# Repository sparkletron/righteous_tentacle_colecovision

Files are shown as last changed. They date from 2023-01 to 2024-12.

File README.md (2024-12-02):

# Righteous Tentacle, Colecovision Reverse Engineering Project
### Schematic and PCB reproduction.

---

  author: Jay Convertino

  date: 2023.03.01

  details: Reverse engineer original PCB to create a schematic and functional replacment board. This only includes the NTSC system.

  license: MIT

---

PCB_Complete|300

## LICENSE
  - All files related to or generated from the KiCAD source fall under the MIT license.
  - All files generated by me, Jay Convertino, fall under the MIT license.
  - All files from other sources fall under the license of their specification.

## RELEASE VERSIONS
### Current
  - 1.0.2.F - Fixed solder mask on expansion bay connector.

### Past
  - 1.0.1.F - Added power and reset switch to case.
  - 1.0.0.F - initial release of revision F main PCB
  - DEV

## Gerbers
  Files available below, to download select the download icon next to the raw icon on right hand upper side of the page.
  - [Main PCB Gerber Archive](schematic/PCB_TOOLS/gerber/MAIN_GERBER.zip)
  - [RF PCB Gerber Archive](schematic/PCB_TOOLS/gerber/RF_GERBER.zip)

## Wiki
  - Please see the [Wiki](../../wiki) for various information.
    - Contains howto's, build notes, bill of materials, project logs, and signal documentation.

## Parts list
  - [Link to Wiki Parts list for the original console](../../wiki/Detailed-Part-Listing-For-Original)
  - [Link to Wiki Parts list for ordering parts](../../wiki/Detailed-Part-Listing-For-Orders)

## Intro

  This recreation of the PCB is for documenation, and reproduction purposes. This mimicks the PCB of the original NTSC revision F main board.

## SOURCES
### Schematic Check
  - Atari HQ Schematic : https://wiki.console5.com/wiki/Colecovision : Dan Boris
  - Atari Age : https://forums.atariage.com/topic/285656-new-colecovision-schematics/ : ChildOfCV

  Special thanks to ChildOfCV. Using his as a check for mine after buzzing out my own board was a great help. His schematic on
  its own is a great resource.

  Did find a few issues with mine vs the ChildOfCV version, my board is a different revision so they will differ in subtle ways.
  Seems to be mostly just cap and resistor values in the RF circuit. Though I did adjust my values on the clock to reflect those
  recommend in the tech manual.

  The Dan Boris schematic is ok, has a few mistakes that I can't recall at the moment. Mentioning it since I did look at it, but
  due to its issues I didn't use it.

## REQUIREMENTS
  - KiCAD v7.X

## BUILD TIPS
  This design is made so anyone can build this. You may send it out to a fab house, you may use a PCB mill, or even etch it.
  This is possible since the components can serve as the plated through hole. Other holes can simply have a solid piece of
  wire inserted and soldered to complete the connection (excess resistor leads is a great option).

  Recommend soldering the cartridge connector first, the CPU makes soldering one side of the pins a bit difficult to do
  without melting the connector.

  There are various questionable routings, these are how the original is done. Some adjustments were made to make some things easier
  for at home builders without plated through holes.

## FILE INFORMATION
  - README.md, is this file.
  - LICENSE.md, is the license file (MIT) for anything create by me, Jay Convertion, that resides in this repository.
  - doc, contains various documents used.
    - datasheets, contains parts used on the original board.
    - refs, sources used for checks
      - Coleco_ADAM_Schematic_-_Delta_Game.png, publicly available schematic of the ADAM
      - Coleco.zip, ChildOfCV schematic for the console and other various parts of the colecovision.
      - colecovision_atari_hq_schematic.pdf, Colecovision console schematic... has errors.
      - tms-doc-annotated.pdf, TMS design document corrected by Nicholas Piegdon
  - models, PCB items and case designes
    - component_search_engine, website 3D files
    - FreeCAD
      - MainBoard, 3D PCB export to step using freecad instead of kicad.
      - parts, parts designed for the PCB by myself and future contributions.
    - inventor_2024
      - base_case, contains ipt/stl files for building a case for the colecovision.
      - OldVersions, inventor files
    - partcommunity, website 3D files
    - kicad, kicad 3D pcb export to step.
  - pics, images take by me or others(watermark added) of the colecovision.
    - 3D, images generated by modeling tools.
    - built, contains all PCBs built
    - build_case, contains all completed cases with PCB.
    - control_pcb, pics of a different Colecovision console pcb (different REV) for comparison.
    - control_unit, pics of a different Colecovision console for comparison.
    - outside_sources, external sources with added watermark.
    - reverse_high_res, scans from a Canon 9600 DPI flatbed scanner of the PCB boards. Compressed to save space.
    - tear_down, images of the parts as they came apart.
    - signals
      - digital, all digital analyzer captures
      - analog, all analog scope captures
  - schematic, contains KiCAD schematic files.
    - coleco_original.kicad_pro, this file is the main project file that contains EVERTHING.
    - *-backups, are folders KiCAD creates to backup the project.
    - PCB_TOOLS
      - gerber, containts all exports from KiCAD
        - main, base PCB
        - rf, modulator PCB
      - GIMP_Placement_Tool, gimp project used to help place parts in the correct locations.
      - main, contains the main PCB extracted from the main project for production.
      - rf, contains RF PCB extracted from the main project for production.
    - lib, external components for KiCAD
      - CONNECTOR_PCBEdge_EXT
      - LOGOS
      - MHPS2273
      - MODELS
      - MOUNTS
      - OS102011MA1QN1
      - PADS
      - POWER_SYMBOLS
      - RCJ-041
      - RF_MODULATORS
      - SWITCHES_THT
      - TE_550841-2
      - VARIABLE_INDUCTORS
      - VINTAGE_AUDIO_SYNTH
      - VINTAGE_RAM
      - VINTAGE_VDP
    - PDF, various KiCAD exports in the PDF format. PCB and/or schematics.

## PCB IMAGE

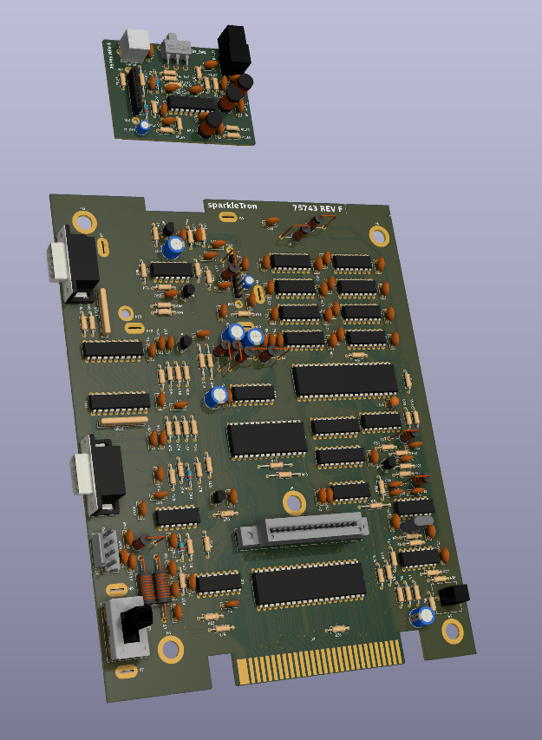
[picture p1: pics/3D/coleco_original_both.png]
pcb_3D_img|300


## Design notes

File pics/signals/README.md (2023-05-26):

# SIGNALS INFO

## Folders
- Analog
All signals in the analog folder are measured using an oscilliscope probe, and include analog AND digitial signals self triggered as a single measurment.

- Digital
All signals in the digital folder are measured using a logic analyizer, and ONLY include digital signals.

## Usage
These captures are only for quick troubleshooting of the device. They are not perfect, though they give a rough idea of what someone should see. If they don't have something similar, there maybe a problem with signal.

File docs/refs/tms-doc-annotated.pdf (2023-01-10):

# Annotated by Nicholas Piegdon 2020-08-01

v1

Gain of two.
1 + 5k/5k = 2
Same components as the red
channel.

With a gain of
three, the blue
output becomes:
B ≈ Y + 2(B-Y)
Both Light Blue
and Dark Blue
will exceed 1.4V.
R54.

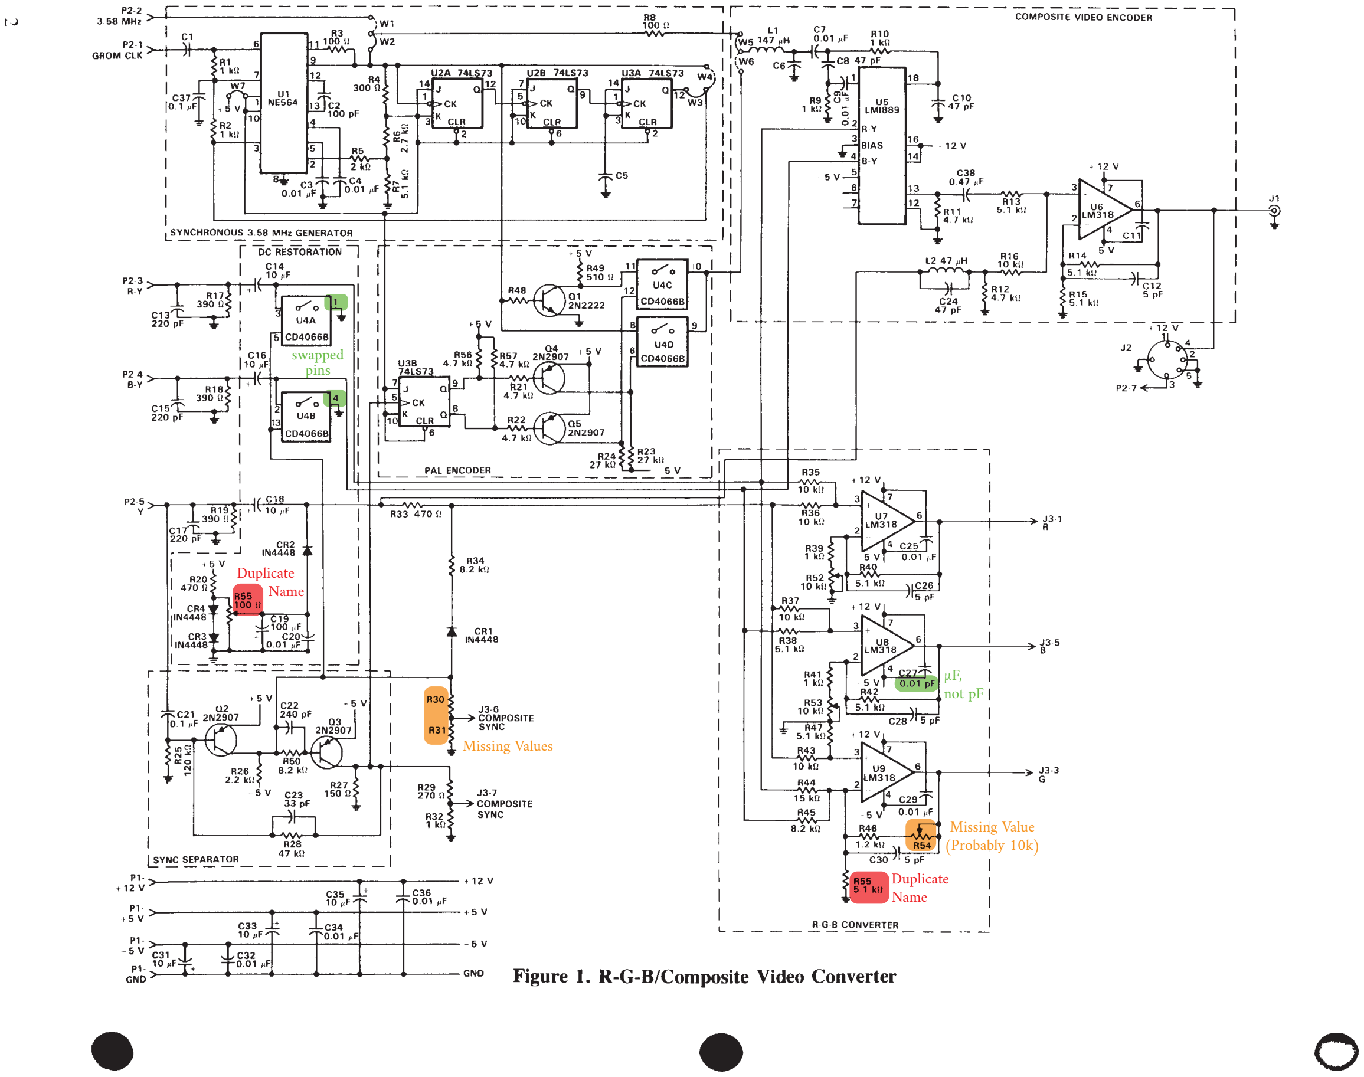
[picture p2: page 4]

Missing Values

Missing Value
(Probably 10k)

Duplicate
Name

Duplicate
Name

µF,
not pF

swapped
pins

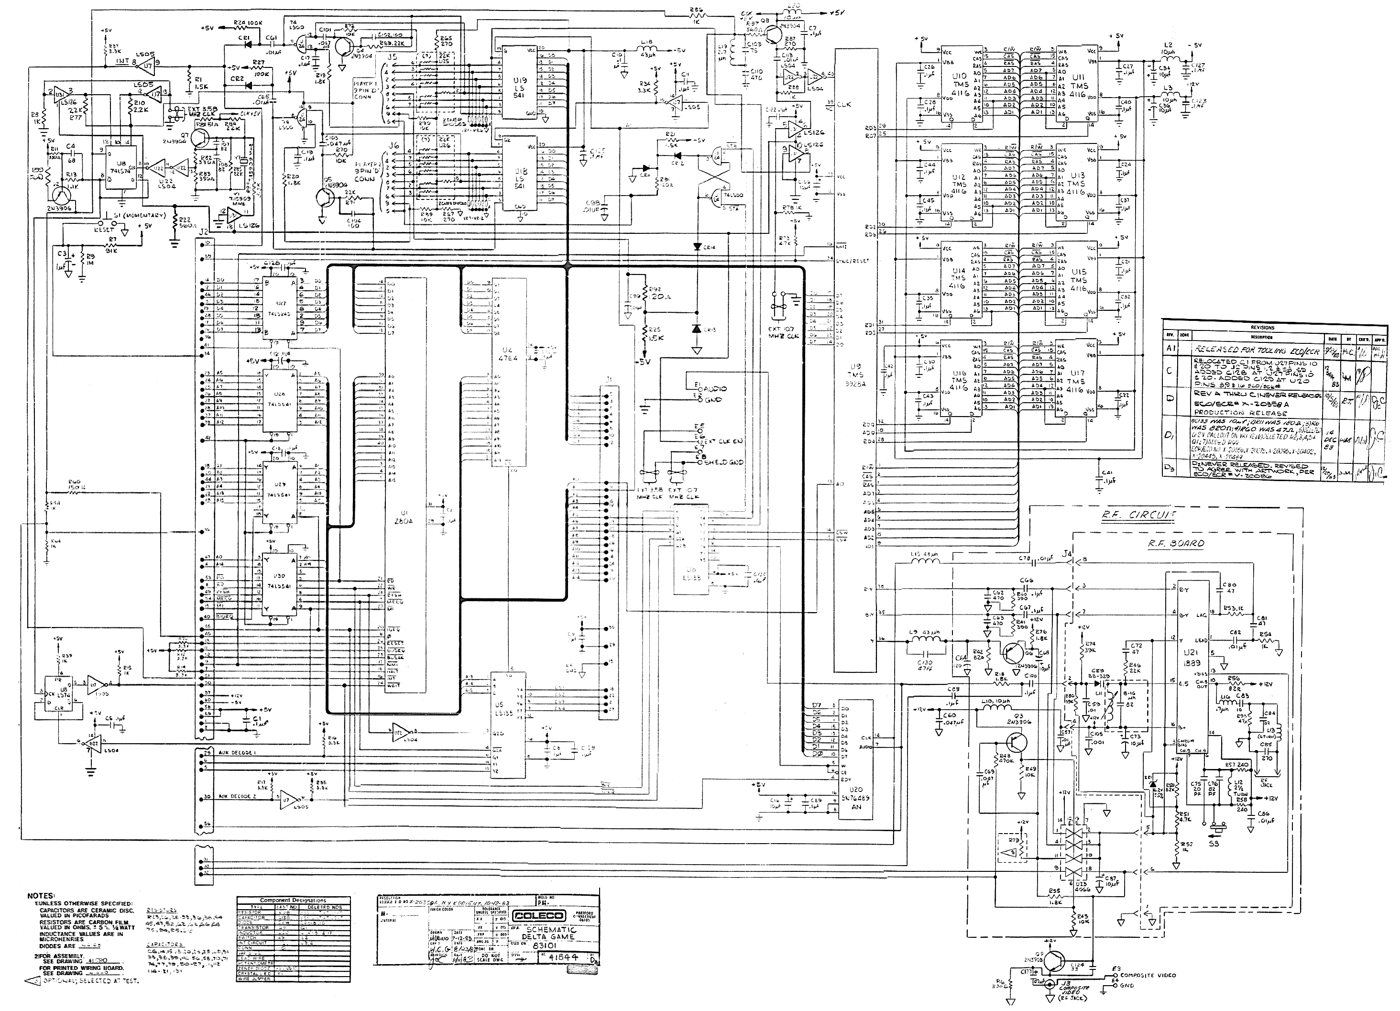
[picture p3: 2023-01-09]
docs/refs/Coleco_ADAM_Schematic_-_Delta_Game.png

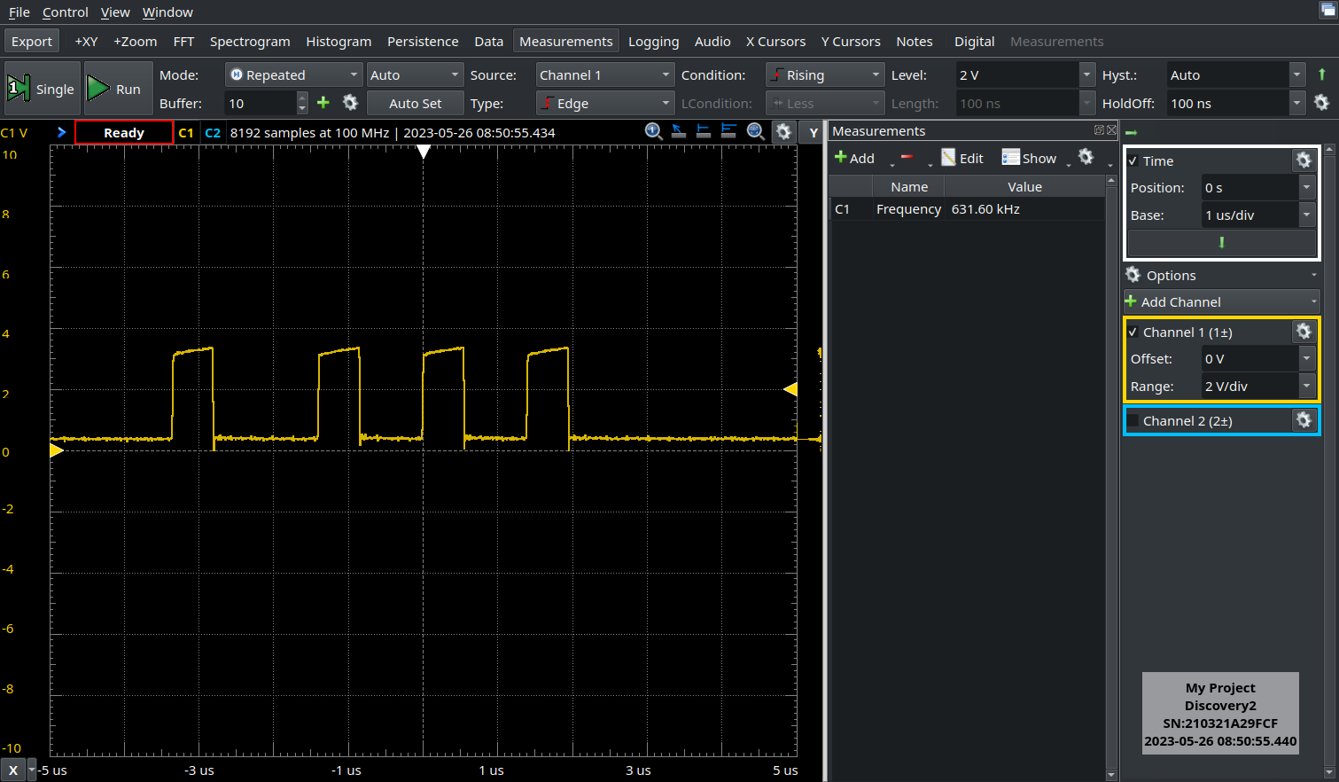
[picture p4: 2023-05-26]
pics/signals/analog/u22_12_rfsh_at_idle_no_game.png

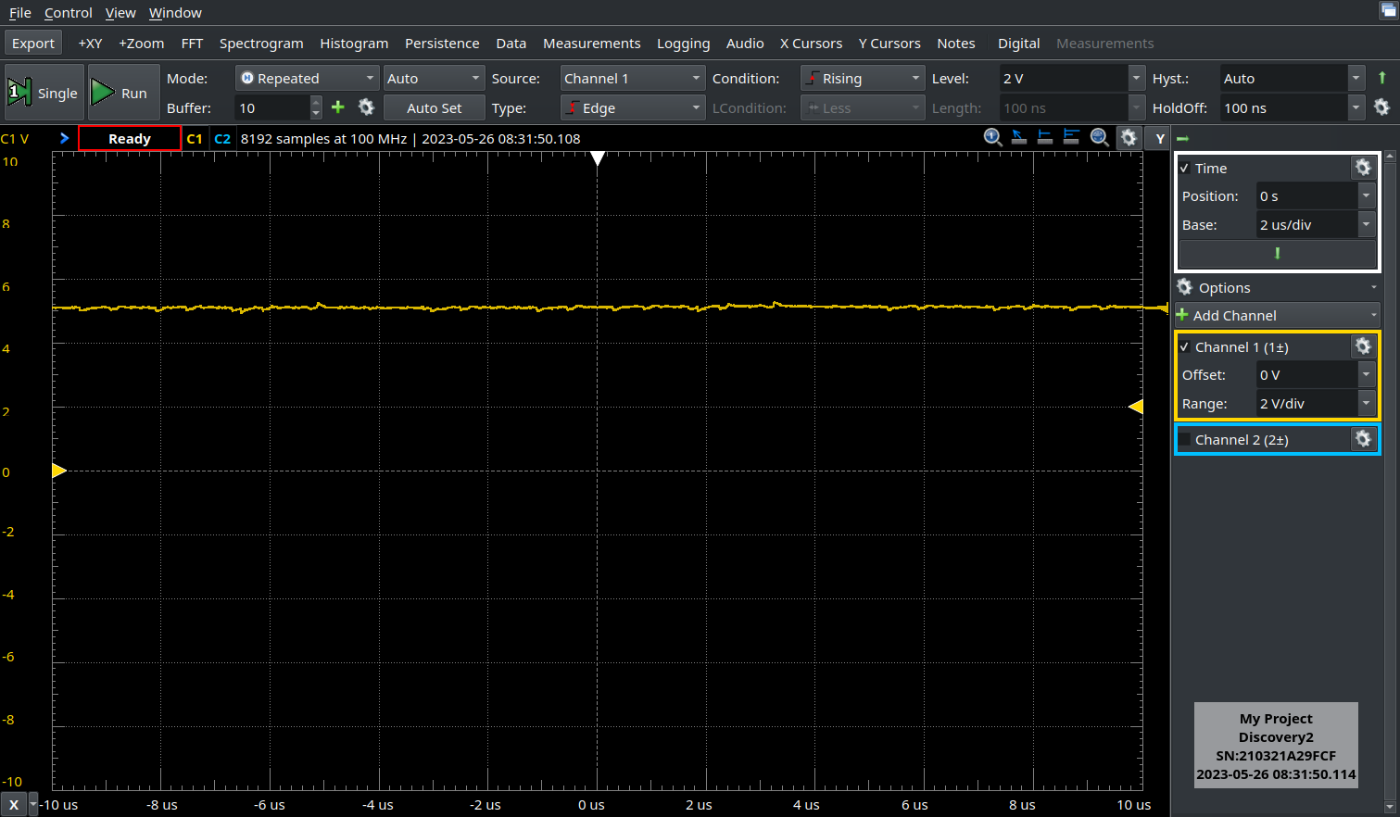
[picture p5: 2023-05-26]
pics/signals/analog/z80_int_at_idle_no_game.png

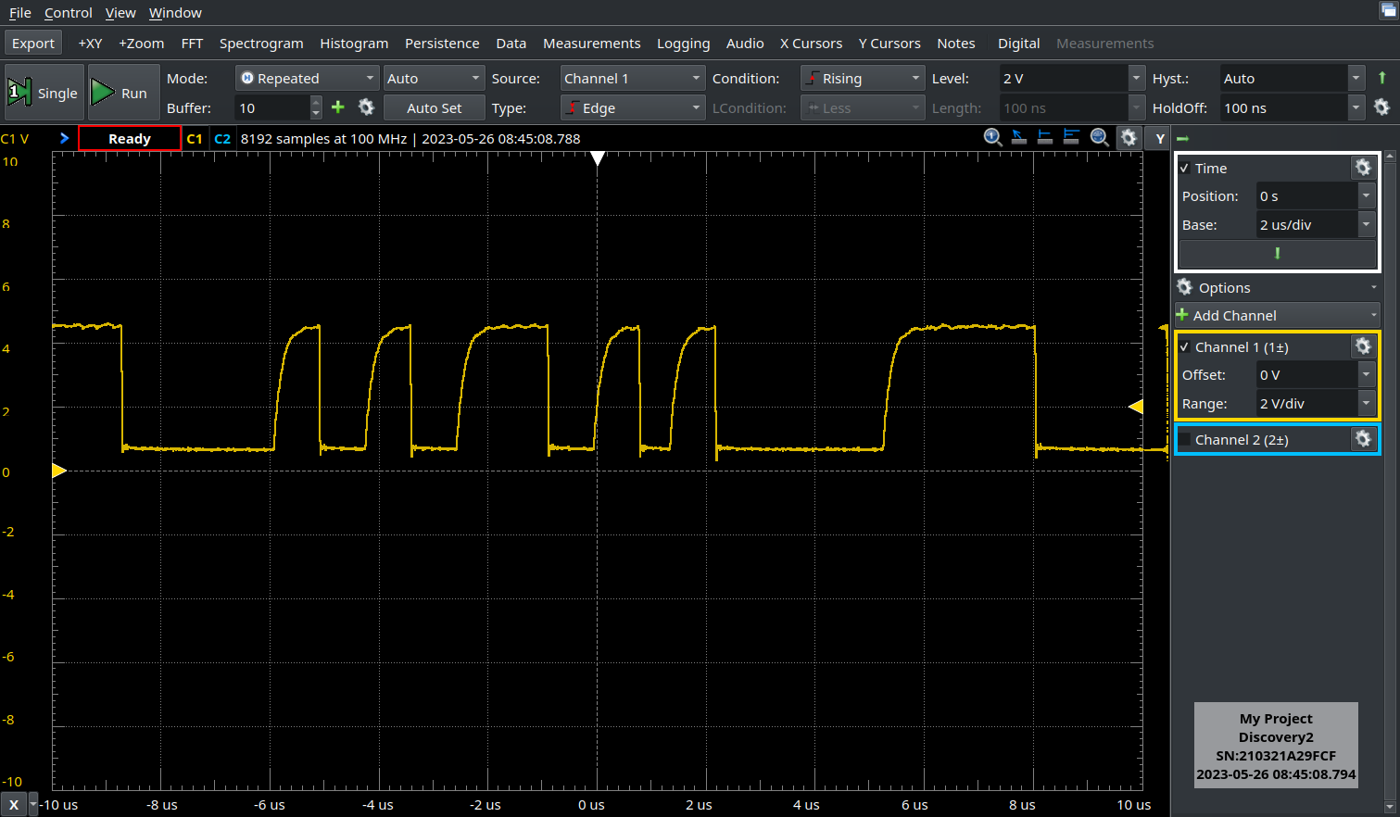
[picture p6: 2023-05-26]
pics/signals/analog/u7_2_ctrl_at_idle_no_game.png

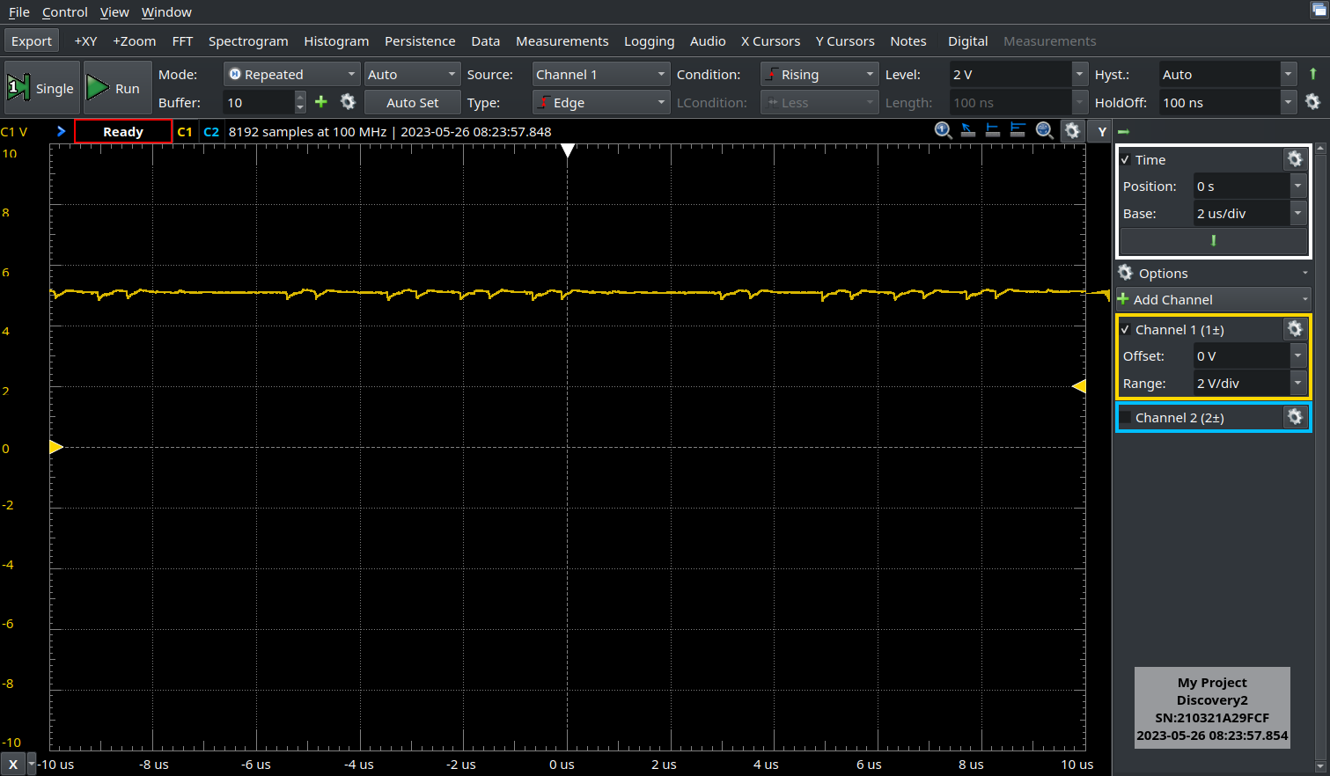
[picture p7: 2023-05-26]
pics/signals/analog/z80_busrq_at_idle_no_game.png

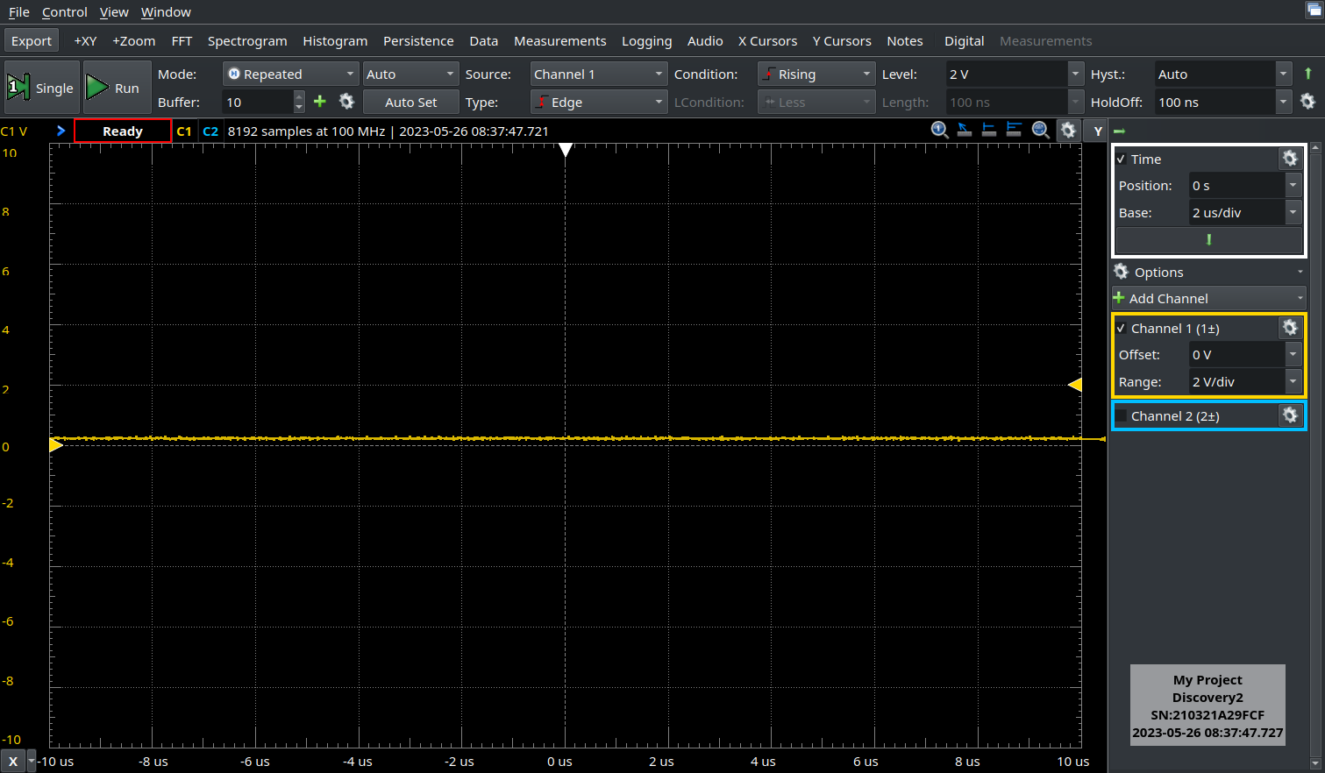
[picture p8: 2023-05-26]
pics/signals/analog/u7_6_aux_at_idle_no_game.png

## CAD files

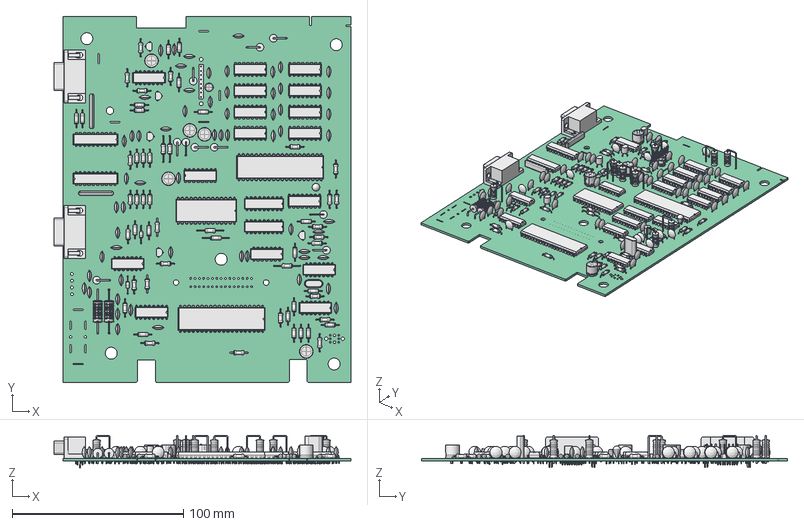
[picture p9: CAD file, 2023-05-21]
models/FreeCAD/MainBoard/main_exports_missing.FCStd
173.6 x 214.0 x 18.9 mm
Pcb_e821
C29_C_Disc_D70mm_W25mm_P500mm_226690d5e42f x 61
L6_L_Axial_L12.8mm_D5.8mm_P25.40mm_Horizontal_Fastron_HBCC_decbe469e87e x 2
R43_R_Axial_DIN0207_L63mm_D25mm_P1016mm_Horizontal_7cedd80d011b x 51
L7_L_Axial_L11.0mm_D4.5mm_P7.62mm_Vertical_Fastron_MECC_598f009e88d8 x 10
WJ1_R_Axial_DIN0207_L63mm_D25mm_P1524mm_Horizontal_ac59213be9fc x 5
C68_CP_Radial_D80mm_P500mm_57de8ce8222a x 5
U8_DIP-14_W7.62mm_df27ad89cb08 x 5
U17_DIP-16_W7.62mm_d55643cdfc89 x 11
J5_DSUB-9_Male_Horizontal_P2.77x2.84mm_EdgePinOffset7.70mm_Housed_ MountingHolesOffset9.12mm_0bdabfa7aa43 x 2
U3_DIP-18_W7.62mm_62ec9f861f82 x 2
UR25_R_Array_SIP8_bea4648dc058 x 2
Q5_TO-92_Wide_9f4aaa88ab23 x 5
Y1_Crystal_HC49-U_Vertical_6ec227dccee9
U18_DIP-20_W7.62mm_b5cb83710fea x 2
CR1_D_DO-35_SOD27_P10.16mm_Horizontal_de2f8e1b5c28 x 2
C87_CP_Radial_D50mm_P250mm_386abb8d7c83
J4A1_PinHeader_1x08_P254mm_Vertical_c9183c638373
C106_CP_Radial_Tantal_D45mm_P250mm_a5643c016bcc
U2_DIP-28_W15.24mm_3ebb076460d0
U9_DIP-40_W15.24mm_d9557ac351a7 x 2

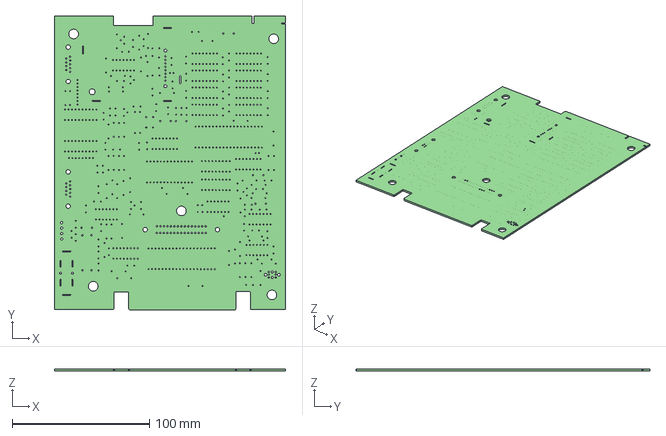
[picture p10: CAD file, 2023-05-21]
schematic/PCB_TOOLS/step/coleco_original_main_only.step
168.4 x 214.0 x 1.60 mm

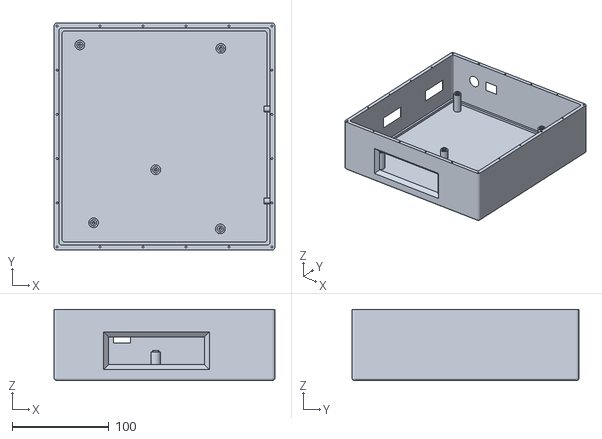
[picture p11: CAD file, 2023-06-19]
models/inventor_2024/Assembly1.stl
228.6 x 234.9 x 73.9

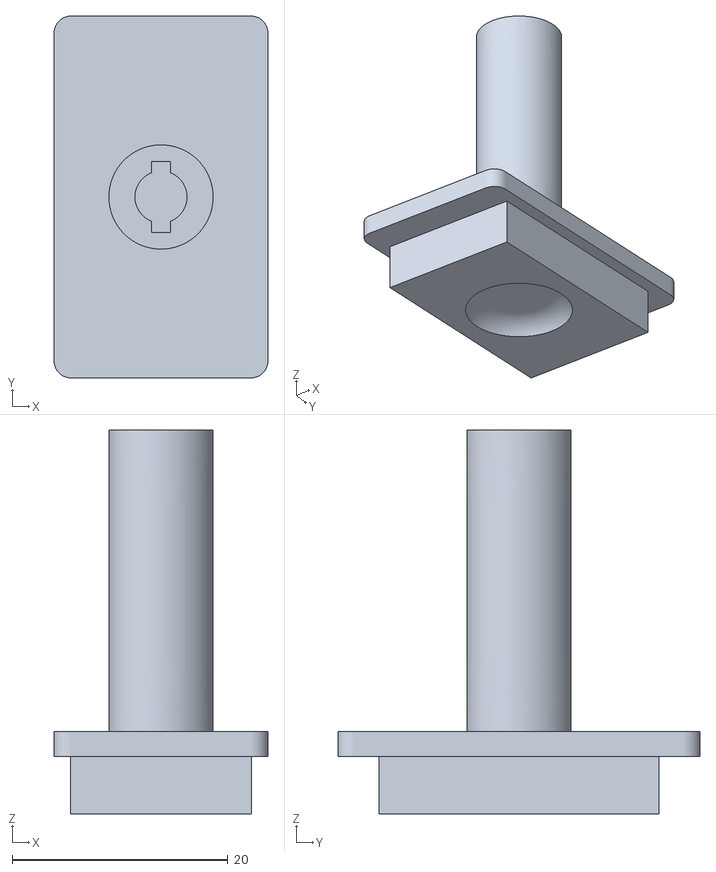
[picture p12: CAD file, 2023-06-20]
models/inventor_2024/base_case/reset_switch.stl
19.8 x 33.5 x 35.6

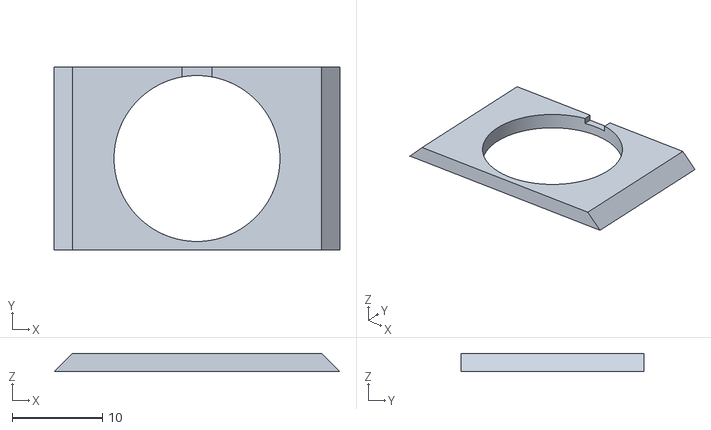
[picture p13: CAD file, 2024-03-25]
models/inventor_2024/org_case_psu_connector.stl
31.8 x 20.3 x 2.03

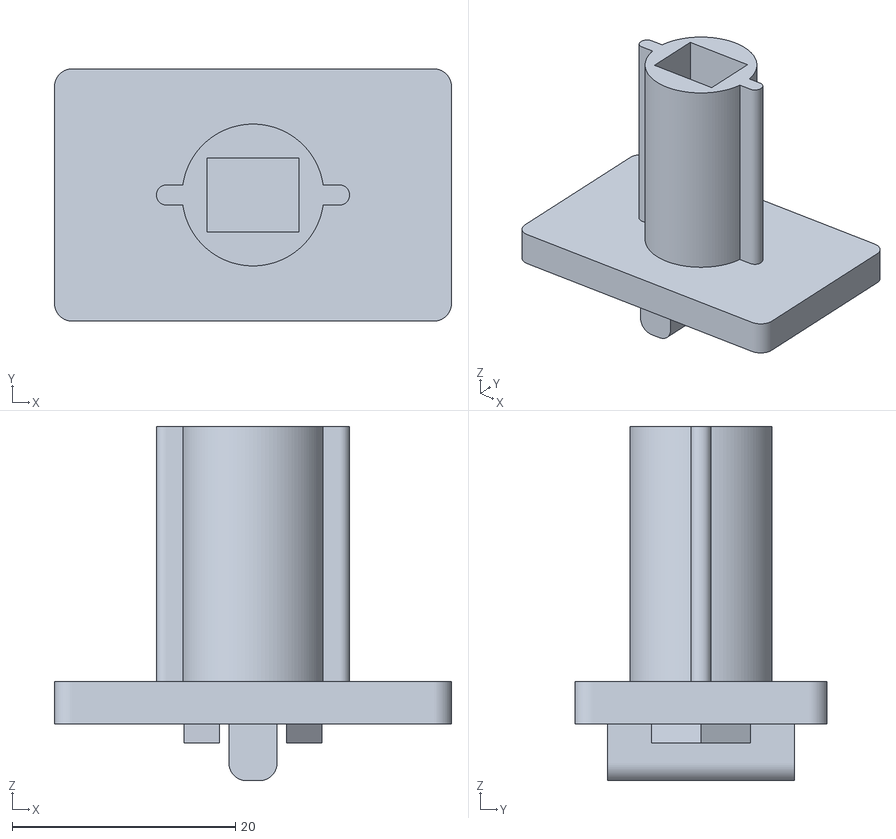
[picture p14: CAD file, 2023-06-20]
models/inventor_2024/base_case/power_switch.stl
35.6 x 22.6 x 31.8

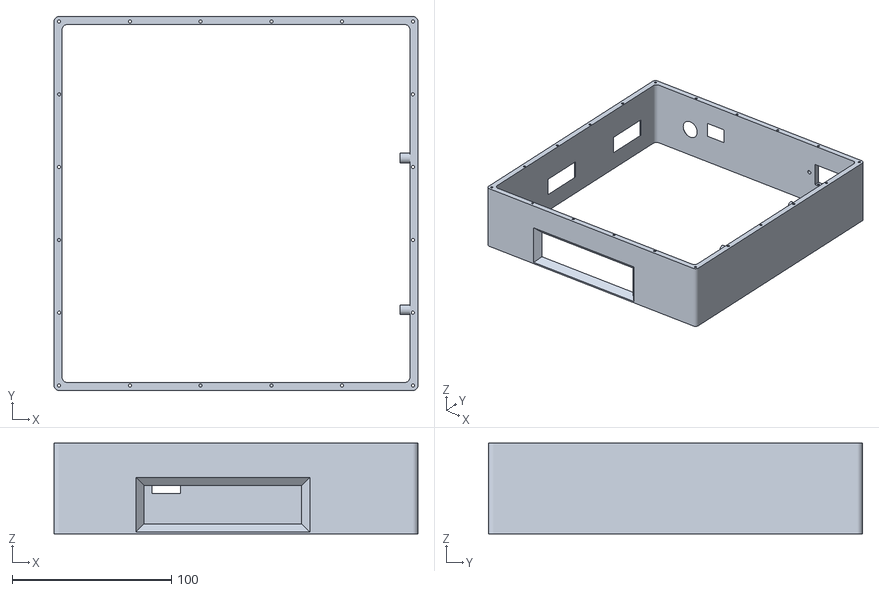
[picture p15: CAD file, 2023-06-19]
models/inventor_2024/base_case/middle_part.stl
228.6 x 234.9 x 57.2

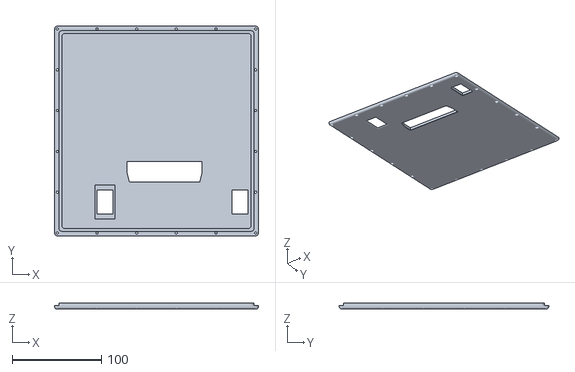
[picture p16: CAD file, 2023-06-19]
models/inventor_2024/base_case/top.stl
228.6 x 234.9 x 7.24

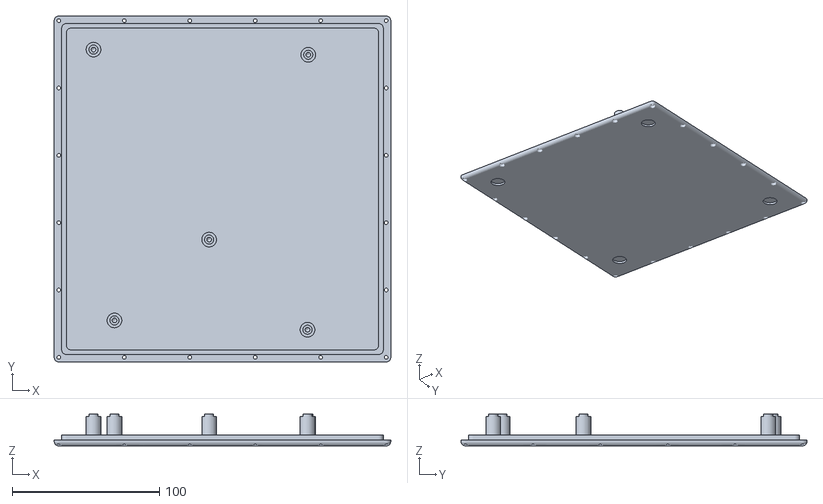
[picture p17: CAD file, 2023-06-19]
models/inventor_2024/base_case/bottom.stl
228.6 x 234.9 x 21.6

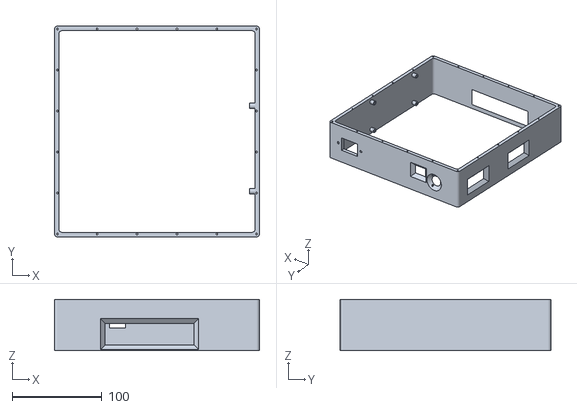
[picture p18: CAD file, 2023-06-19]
models/inventor_2024/base_case/middle.stl
228.6 x 235.0 x 57.2

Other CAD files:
models/FreeCAD/MainBoard/main_exports_missing-coleco_original_main_only/Board_Geoms_e821.iam
models/FreeCAD/MainBoard/main_exports_missing-coleco_original_main_only/C106_CP_Radial_Tantal_D45mm_P250mm_a5643c016bcc.ipt
models/FreeCAD/MainBoard/main_exports_missing-coleco_original_main_only/C29_C_Disc_D70mm_W25mm_P500mm_226690d5e42f.ipt
models/FreeCAD/MainBoard/main_exports_missing-coleco_original_main_only/C68_CP_Radial_D80mm_P500mm_57de8ce8222a.ipt
models/FreeCAD/MainBoard/main_exports_missing-coleco_original_main_only/C87_CP_Radial_D50mm_P250mm_386abb8d7c83.ipt
models/FreeCAD/MainBoard/main_exports_missing-coleco_original_main_only/CR1_D_DO-35_SOD27_P10.16mm_Horizontal_de2f8e1b5c28.ipt
models/FreeCAD/MainBoard/main_exports_missing-coleco_original_main_only/J4A1_PinHeader_1x08_P254mm_Vertical_c9183c638373.ipt
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

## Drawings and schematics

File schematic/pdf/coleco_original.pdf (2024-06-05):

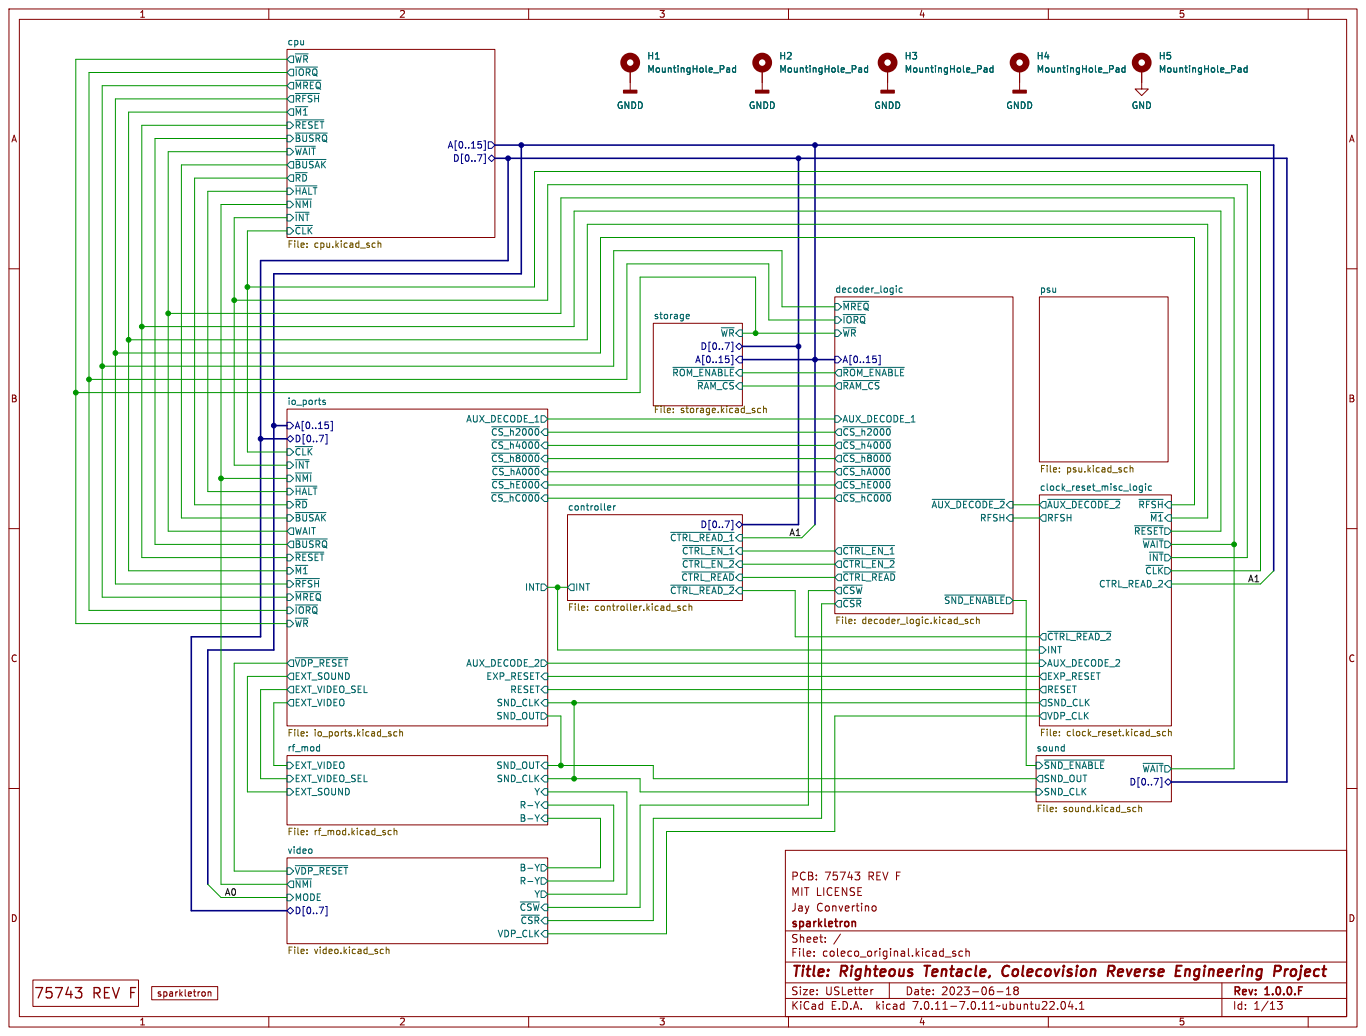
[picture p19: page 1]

Id: 1/13 Title: Righteous Tentacle, Colecovision Reverse Engineering Project File: coleco_original.kicad_sch Sheet: / sparkletron

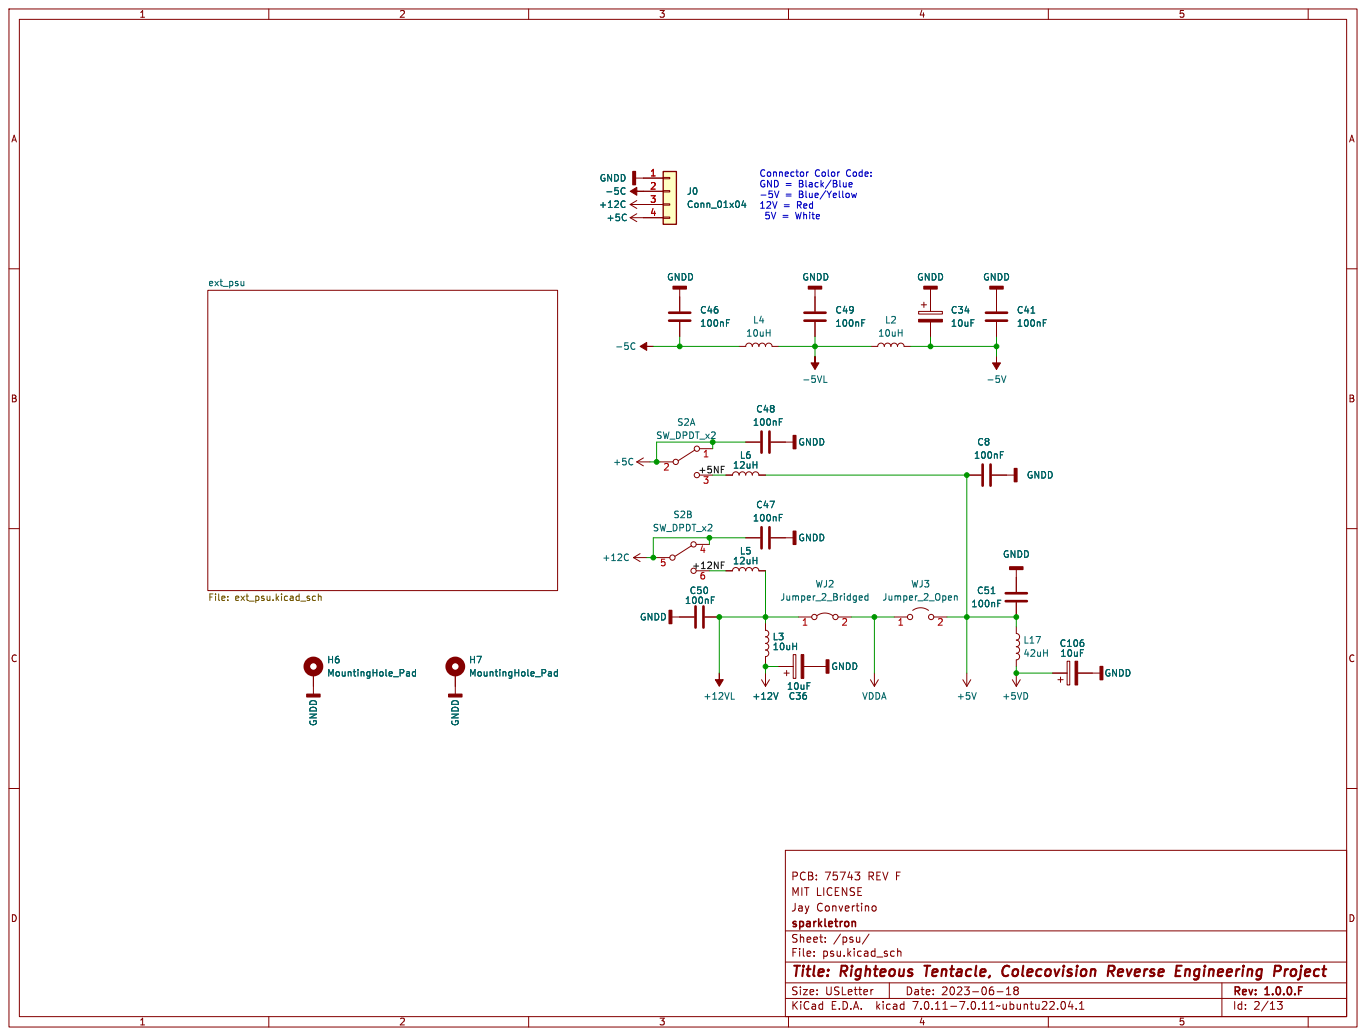
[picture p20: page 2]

Jay Convertino MIT sparkletron | LICENSE

E.D.A. kicad 7.0.11-7.0.11~ubuntu22.04.1 Size: USLetter Rev: 1.0.0.F Id: 2/13 Title: Righteous Tentacle, Colecovision Reverse Engineering Project File: psu.kicad_sch Sheet: /psu/ | D Date: 2023-06-18 KiCad

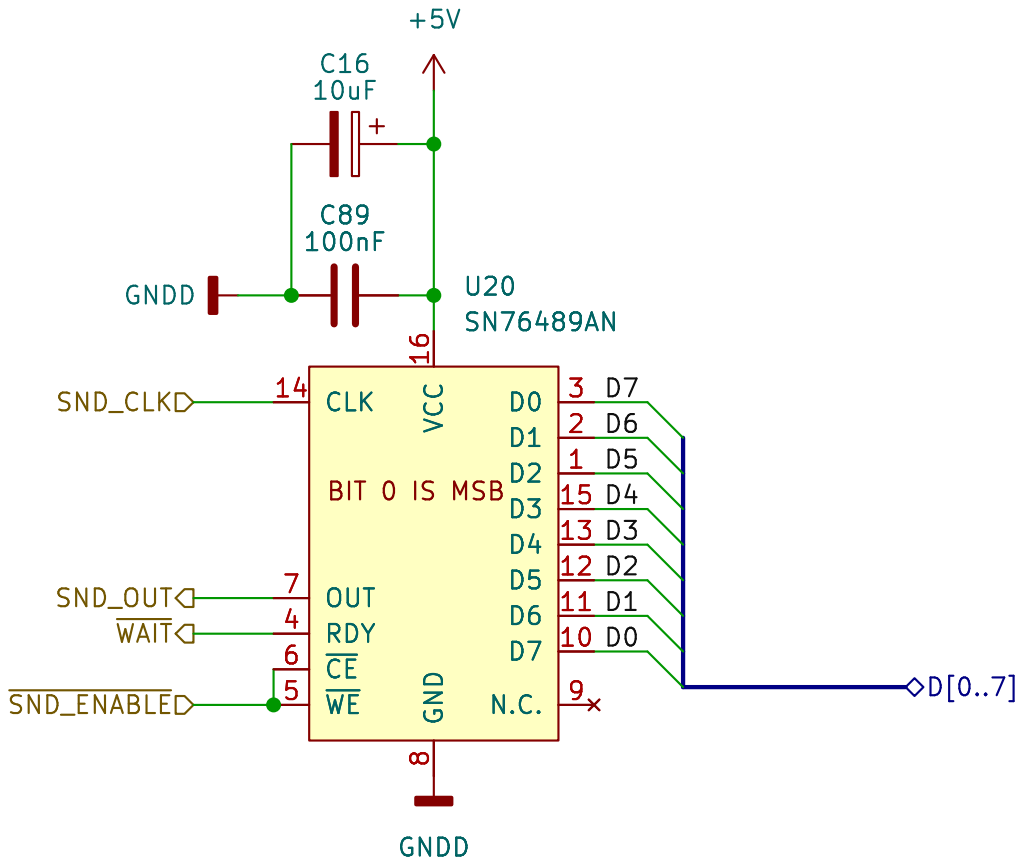
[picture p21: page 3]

Id: 4/13 Title: Righteous Tentacle, Colecovision Reverse Engineering Project File: sound.kicad_sch Sheet: /sound/ sparkletron

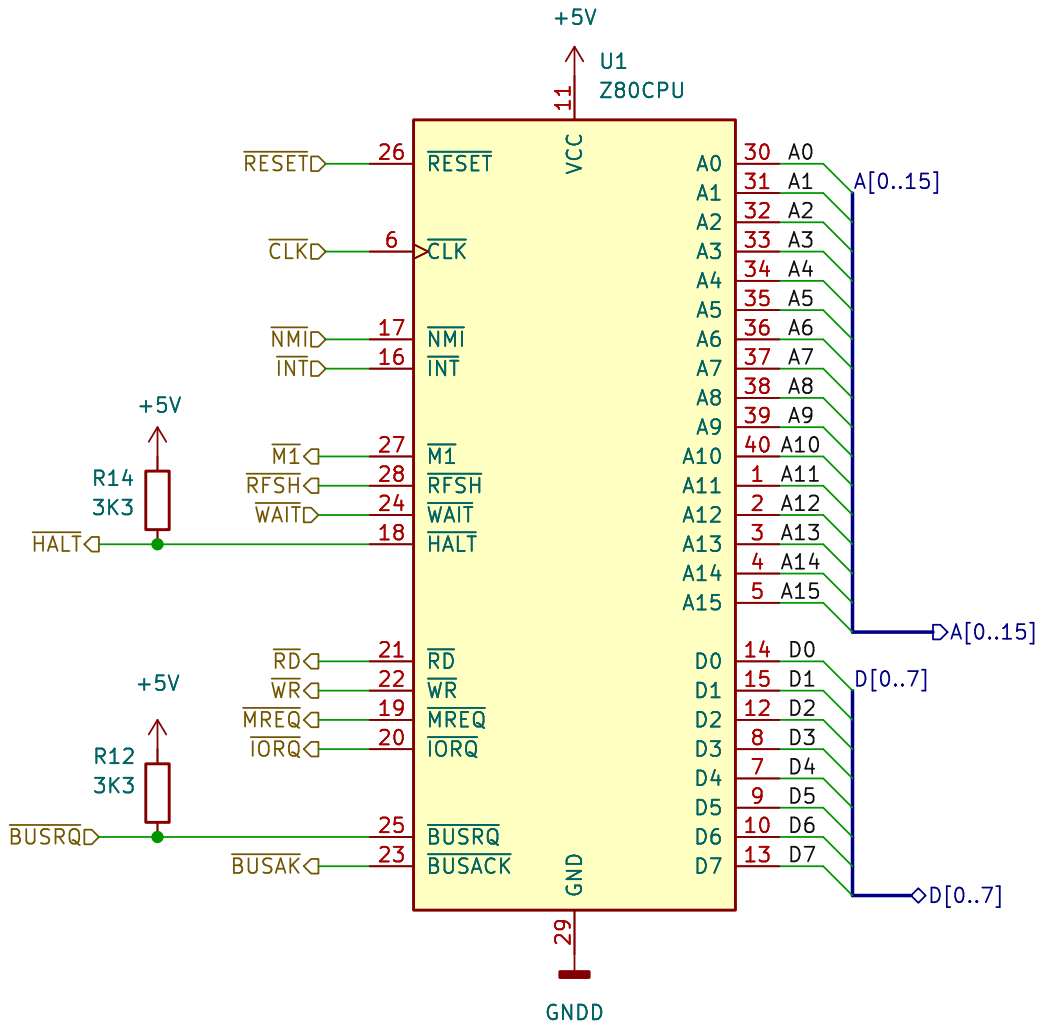
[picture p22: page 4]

Jay Convertino MIT sparkletron | LICENSE

E.D.A. kicad 7.0.11-7.0.11~ubuntu22.04.1 Size: USLetter Rev: 1.0.0.F Id: 5/13 Title: Righteous Tentacle, Colecovision Reverse Engineering Project File: cpu.kicad_sch Sheet: /cpu/ | D Date: 2023-06-18 KiCad

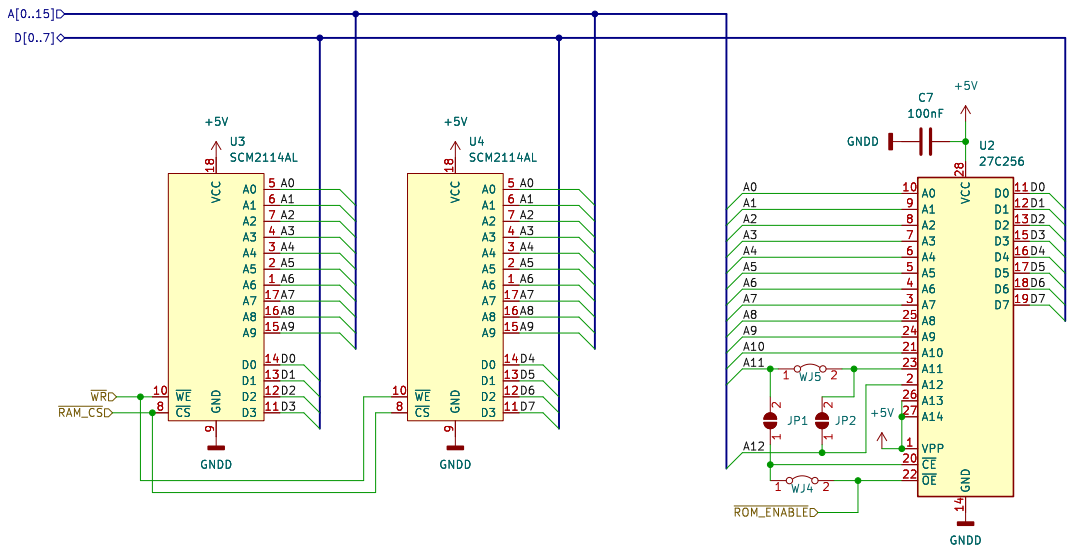
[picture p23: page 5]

sparkletron
Id: 6/13 Title: Righteous Tentacle, Colecovision Reverse Engineering Project File: storage.kicad_sch Sheet: /storage/

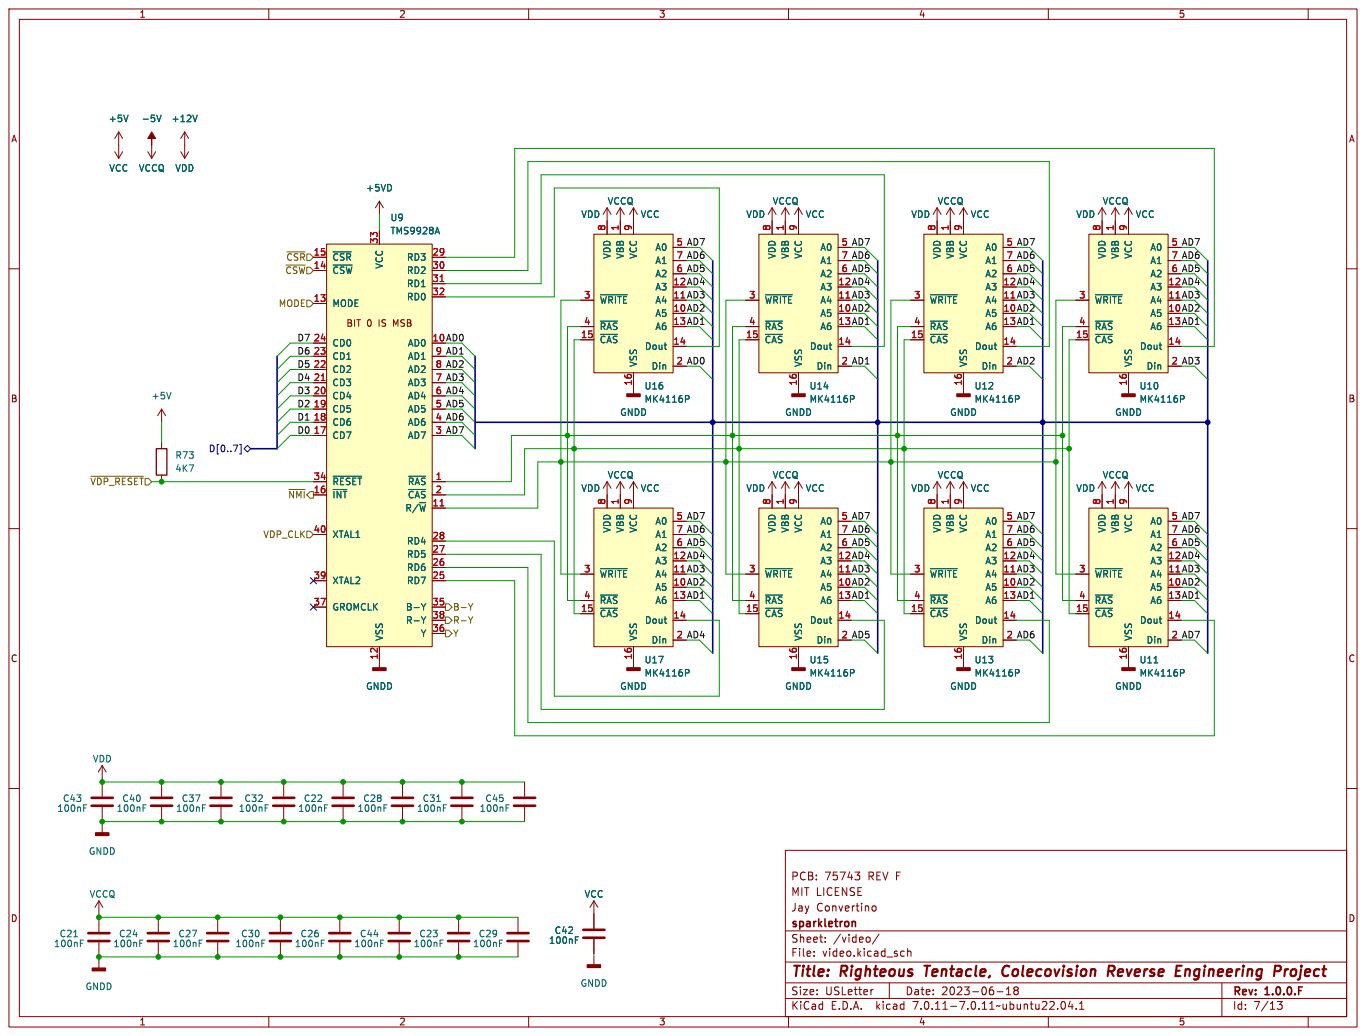
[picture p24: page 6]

Id: 7/13 Title: Righteous Tentacle, Colecovision Reverse Engineering Project File: video.kicad_sch Sheet: /video/ sparkletron

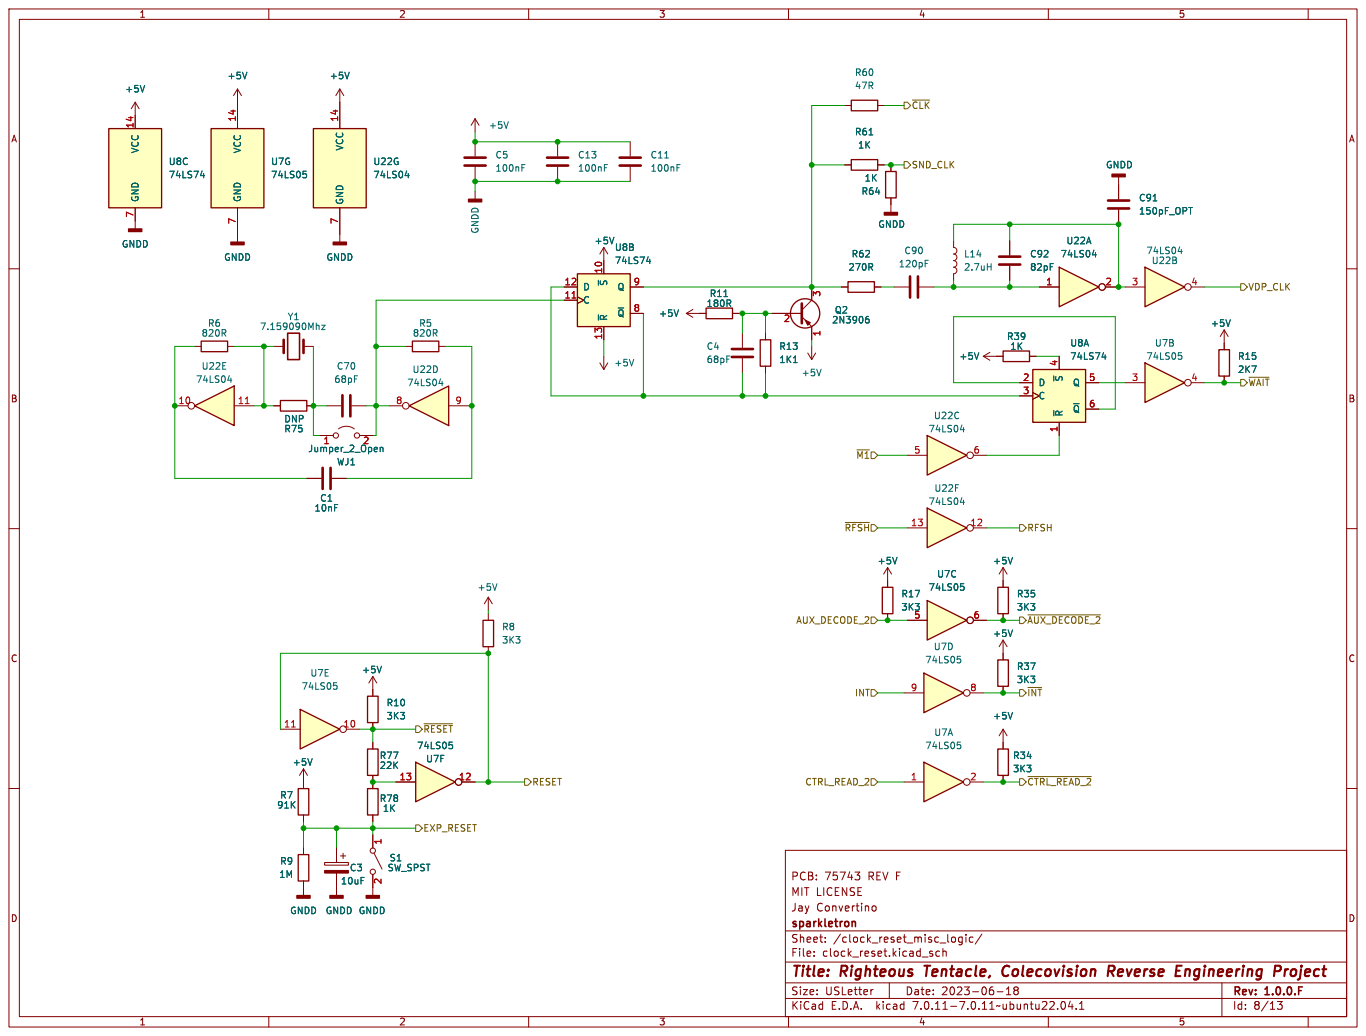
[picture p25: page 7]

sparkletron
Id: 8/13 Title: Righteous Tentacle, Colecovision Reverse Engineering Project File: clock_reset.kicad_sch Sheet: /clock_reset_misc_logic/

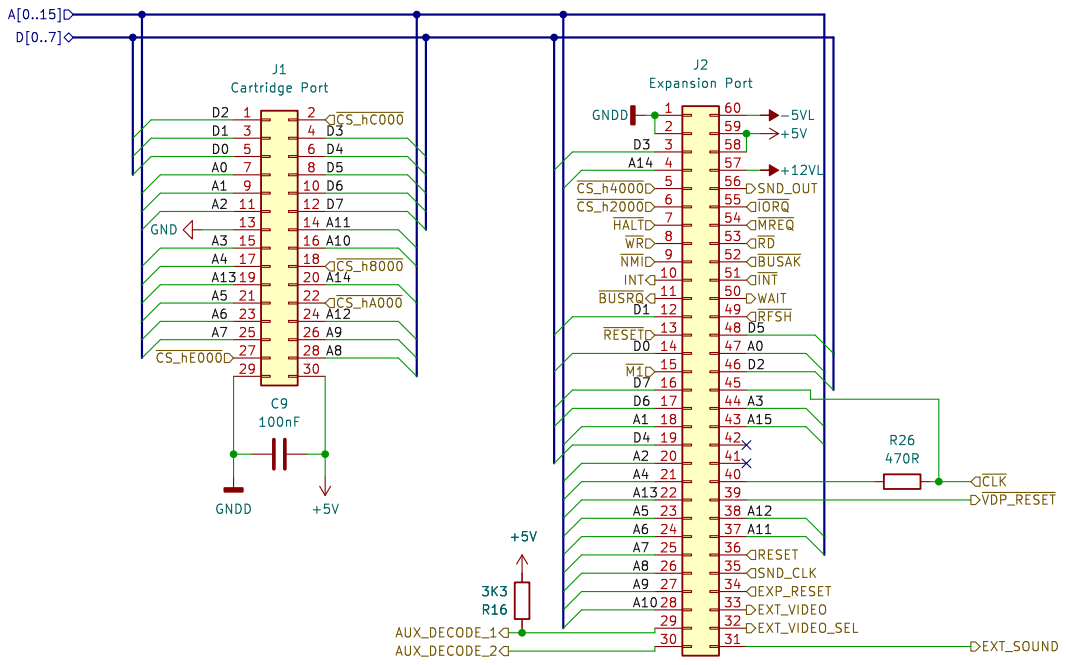
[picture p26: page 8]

Jay Convertino MIT sparkletron | LICENSE

E.D.A. | kicad 7.0.11-7.0.11~ubuntu22.04.1 Size: USLetter Rev: 1.0.0.F Id: 9/13 Title: Righteous Tentacle, Colecovision Reverse Engineering Project File: io_ports.kicad_sch Sheet: /io_ports/ | D Date: 2023-06-18 KiCad

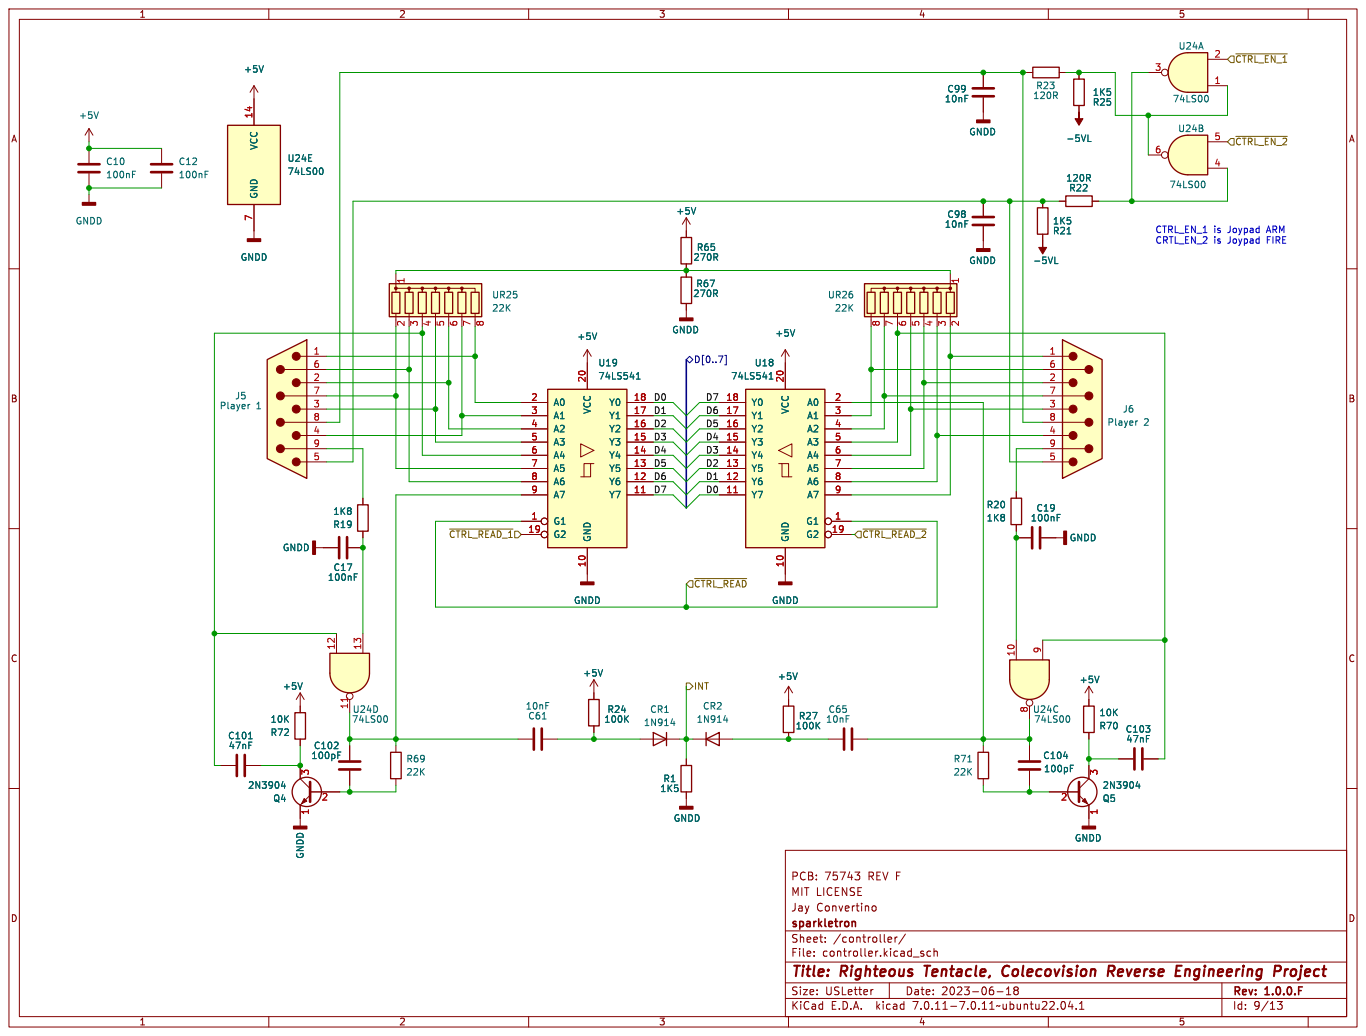
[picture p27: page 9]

CRTL_EN_2 is Joypad FIRE GNDD
GNDD

Id: 9/13 Title: Righteous Tentacle, Colecovision Reverse Engineering Project File: controller.kicad_sch Sheet: /controller/ sparkletron

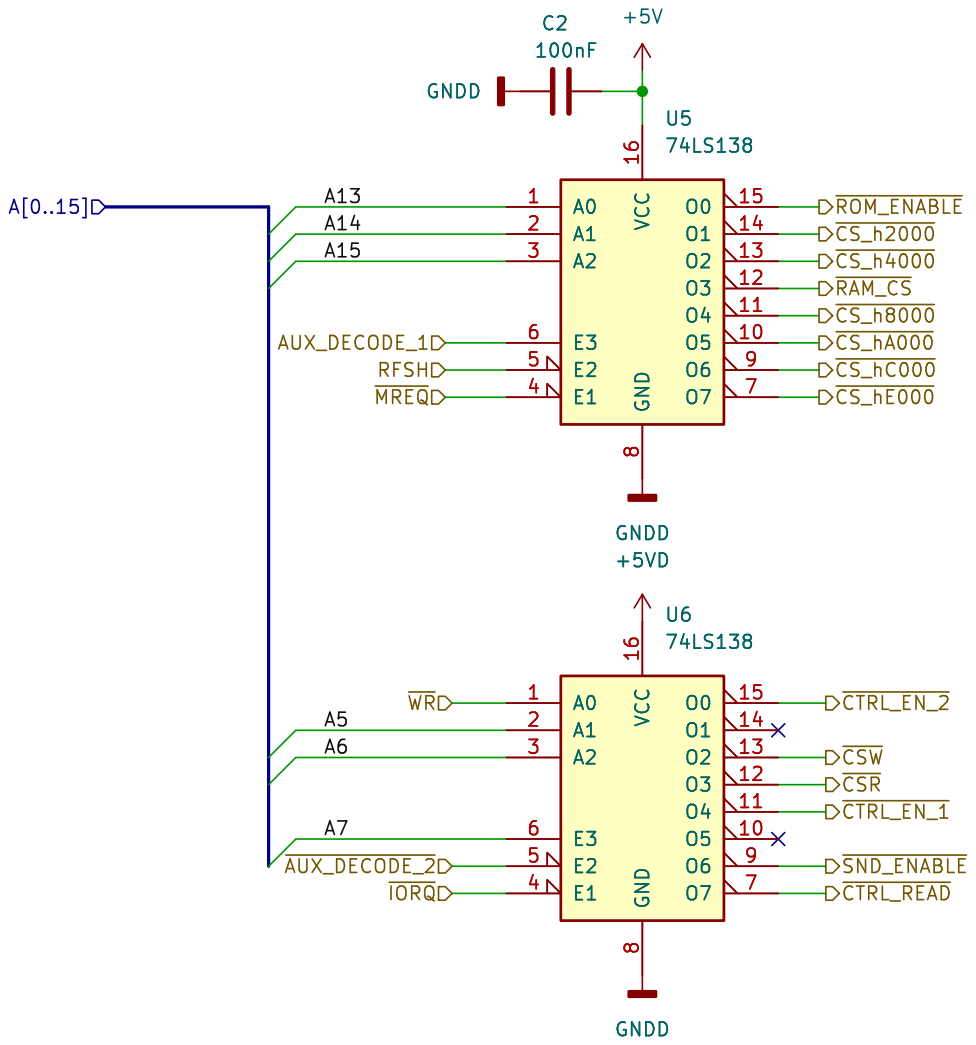
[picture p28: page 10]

sparkletron
Id: 10/13 Title: Righteous Tentacle, Colecovision Reverse Engineering Project File: decoder_logic.kicad_sch Sheet: /decoder_logic/

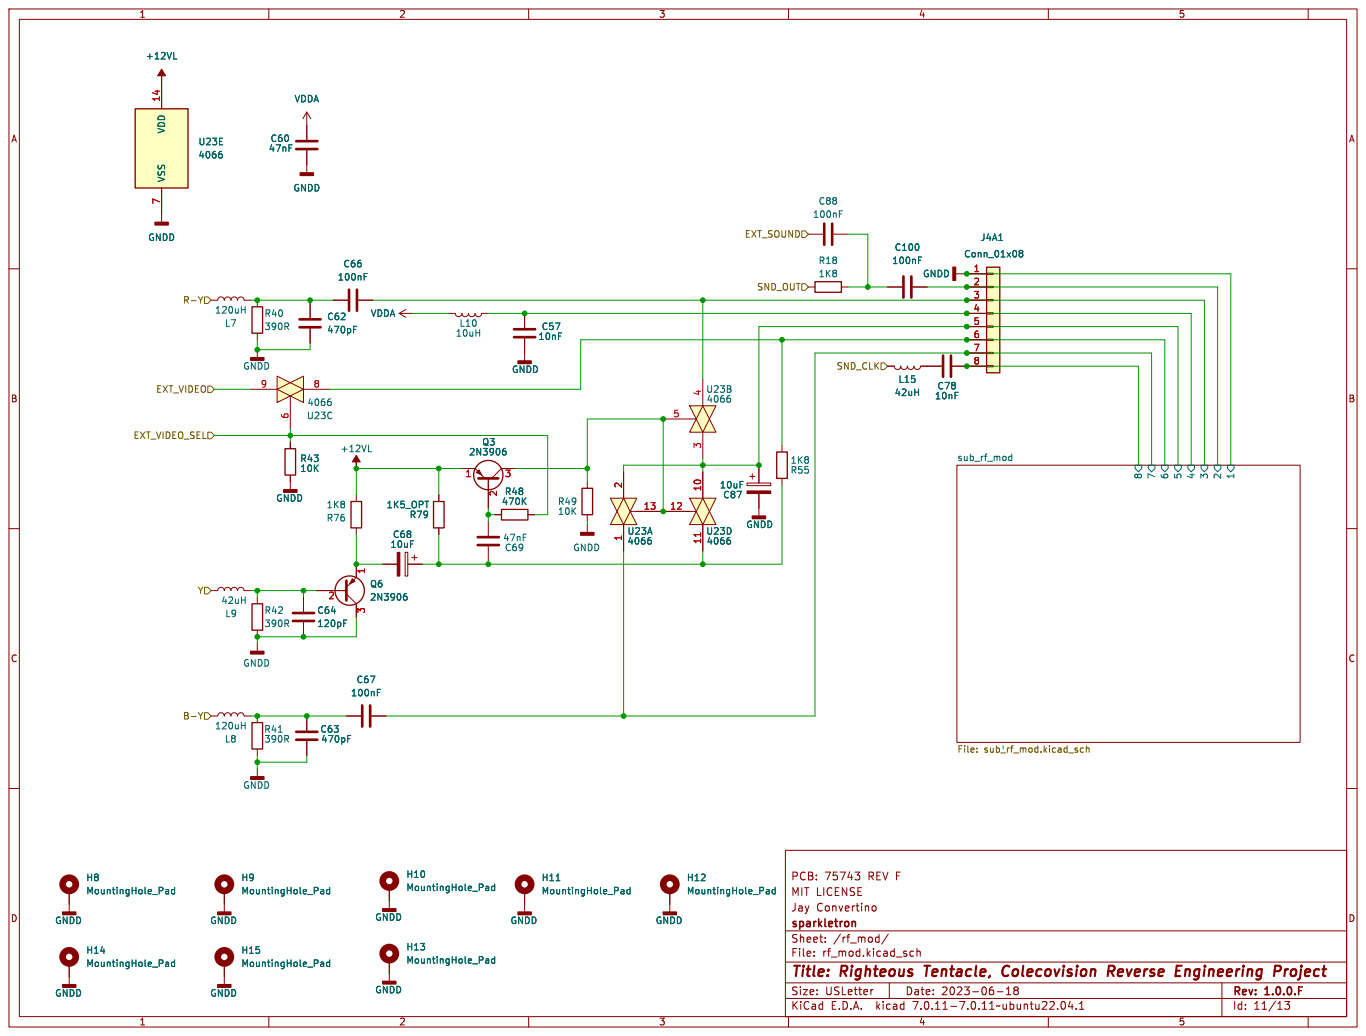
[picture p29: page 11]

sparkletron
Id: 11/13 Title: Righteous Tentacle, Colecovision Reverse Engineering Project File: rf_mod.kicad_sch Sheet: /rf_mod/

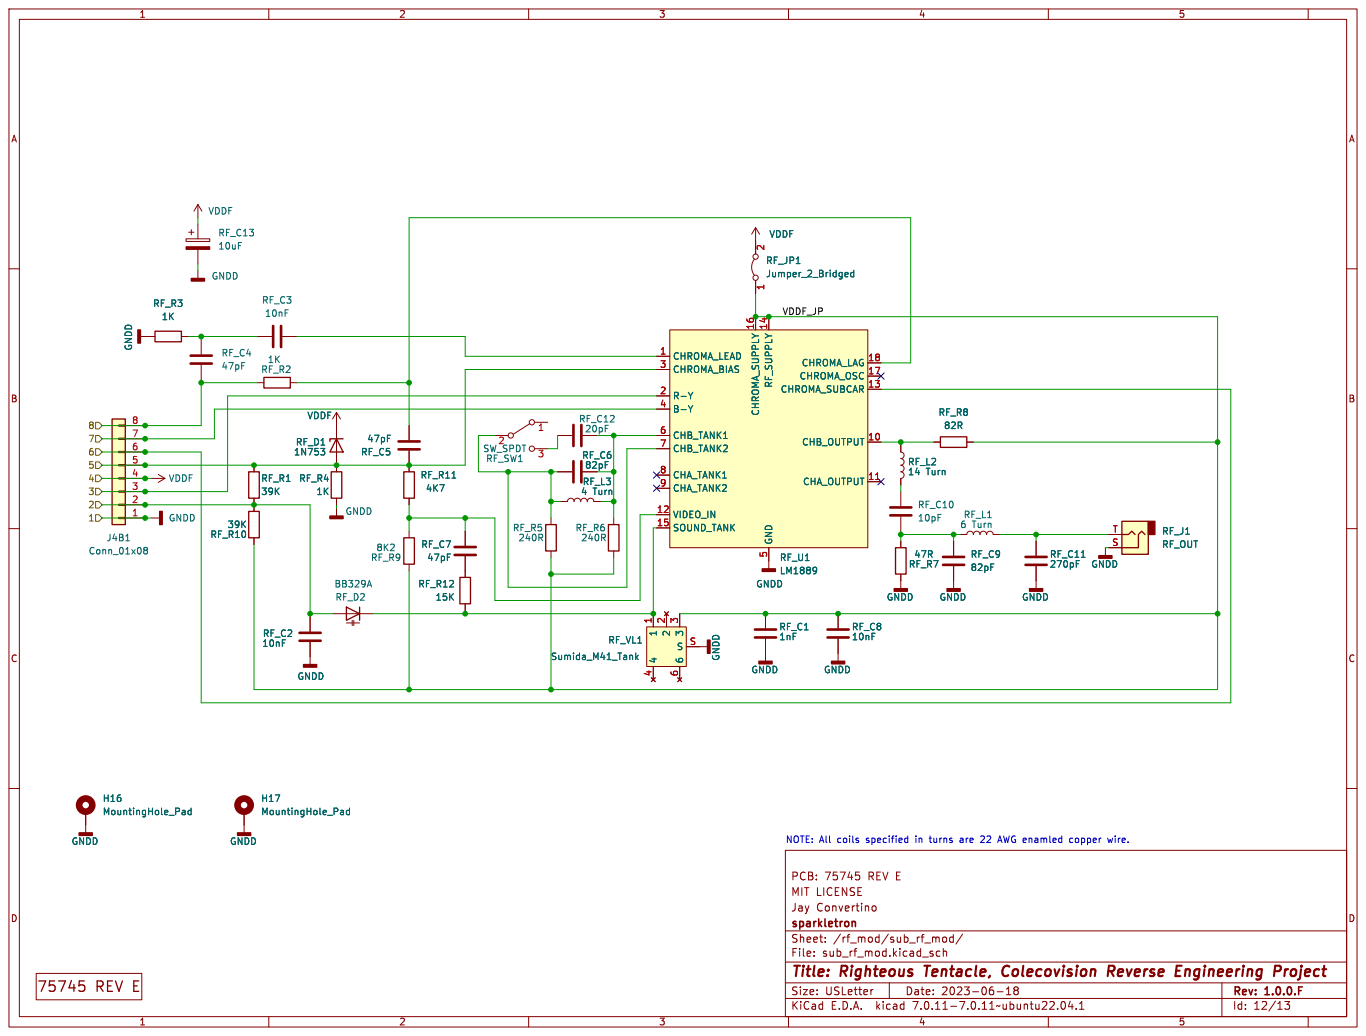
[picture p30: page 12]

sparkletron
Id: 12/13 Title: Righteous Tentacle, Colecovision Reverse Engineering Project File: sub_rf_mod.kicad_sch Sheet: /rf_mod/sub_rf_mod/


Enclosed PSU: - Mean Well GP25A13A-R1B

Jay Convertino MIT sparkletron | LICENSE

E.D.A. | kicad 7.0.11-7.0.11~ubuntu22.04.1 Size: USLetter Rev: 1.0.0.F Id: 13/13 Title: Righteous Tentacle, Colecovision Reverse Engineering Project File: ext_psu.kicad_sch Sheet: /psu/ext_psu/ | D Date: 2023-06-18 KiCad

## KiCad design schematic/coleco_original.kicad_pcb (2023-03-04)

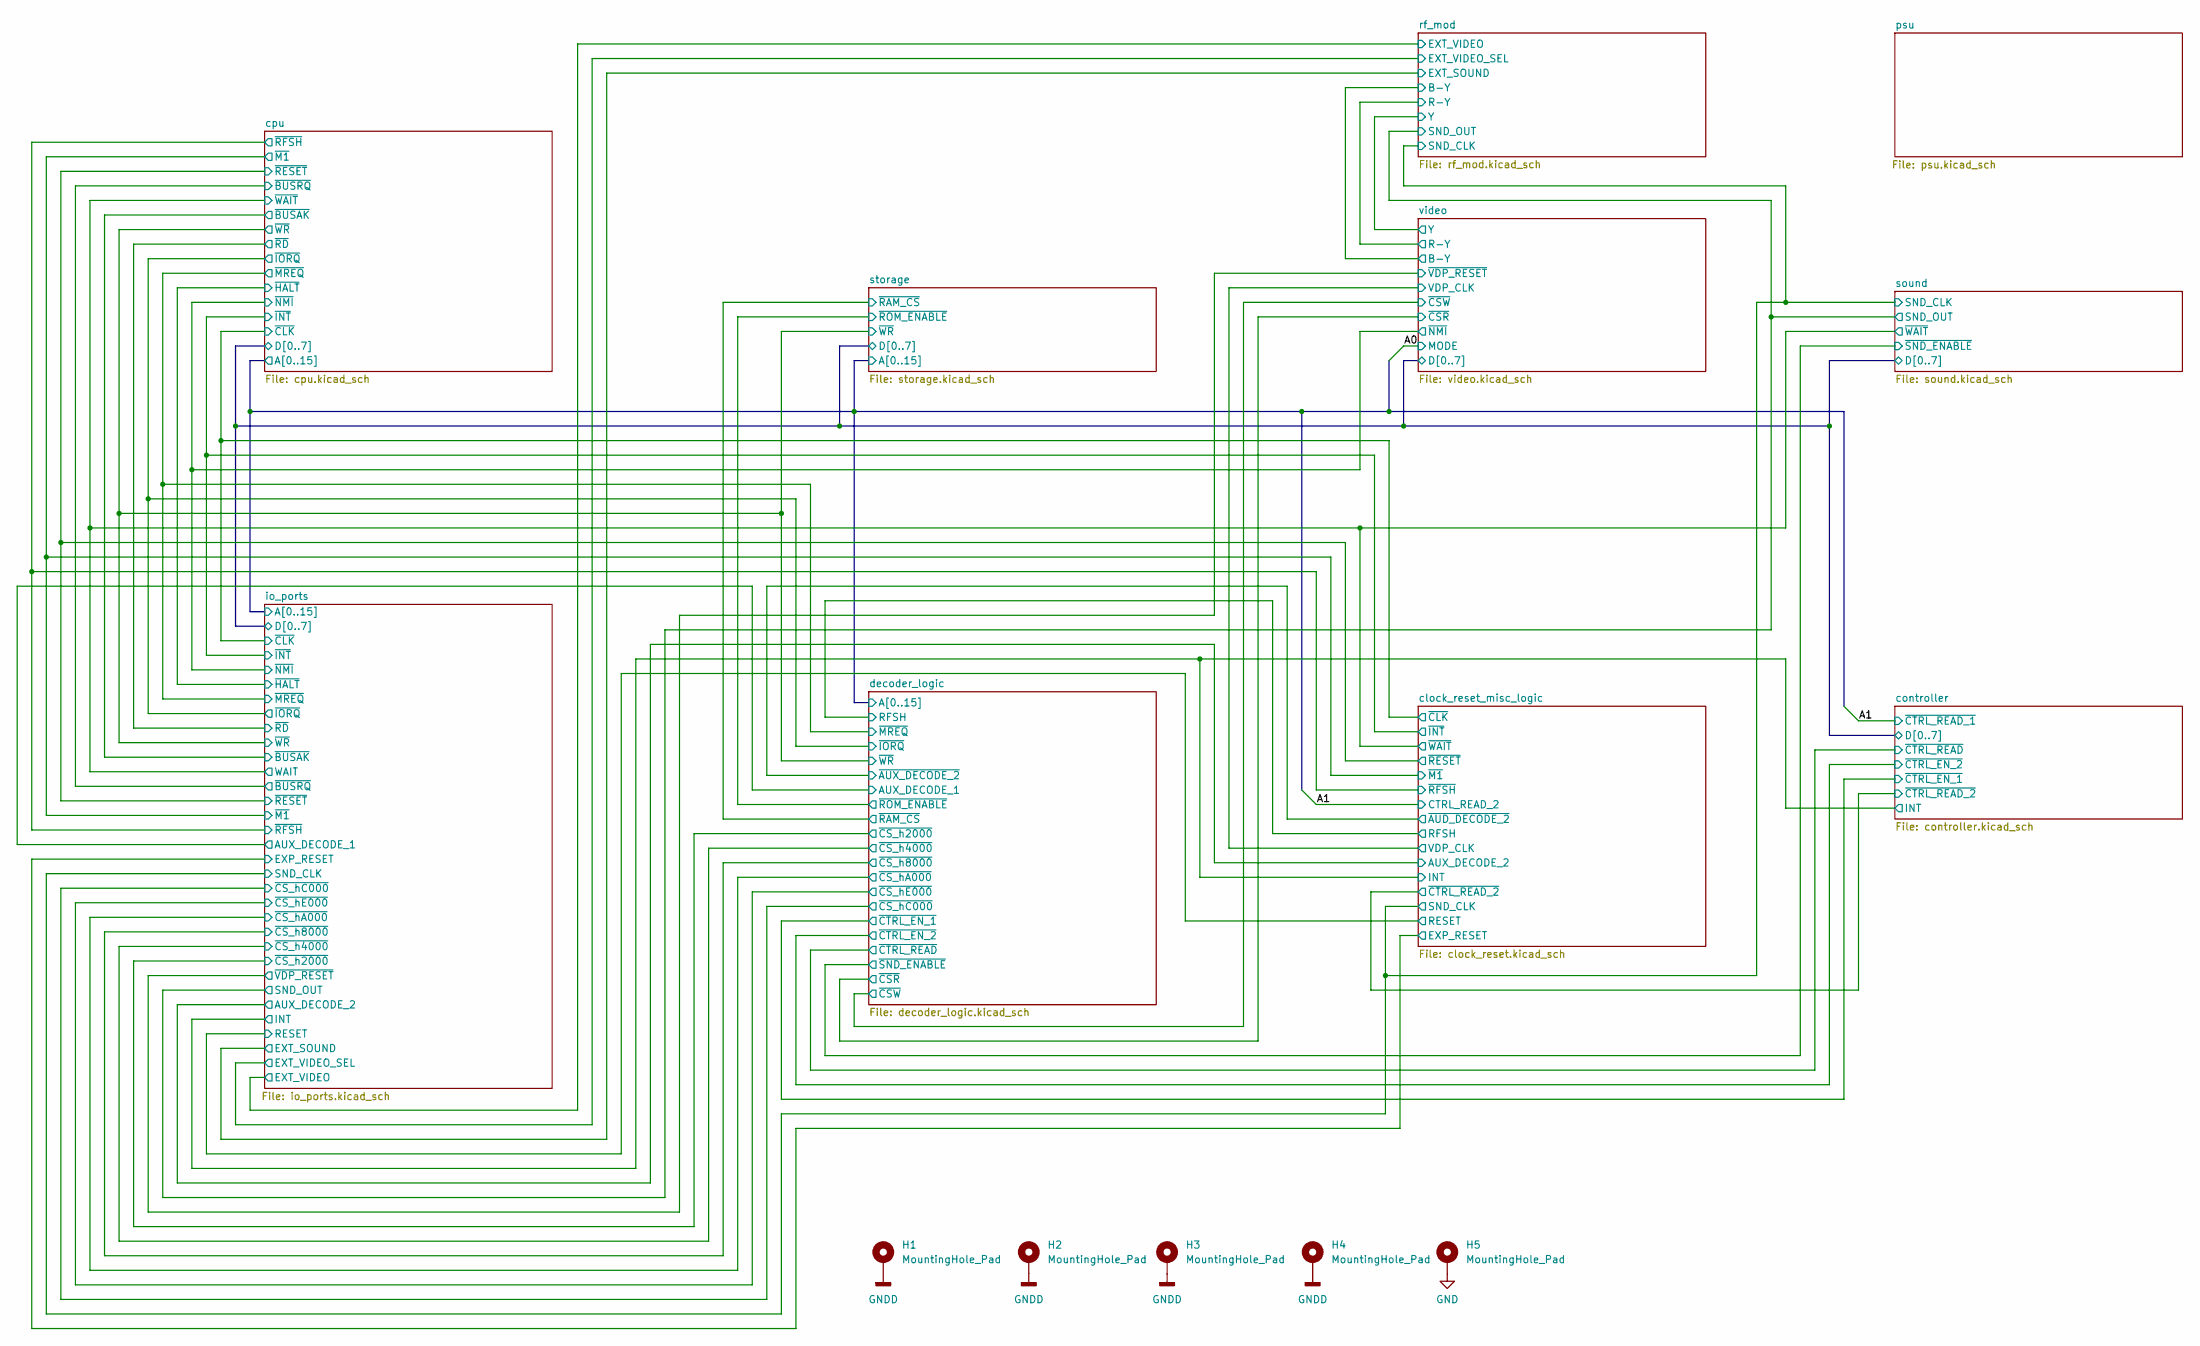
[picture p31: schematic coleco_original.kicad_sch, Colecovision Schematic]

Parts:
H1, H2, H3, H4, H5: MountingHole_Pad; MountingHole_5.3mm_M5_ISO14580_Pad

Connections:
GND: H5.1; also elsewhere on the board
GNDD: H1.1, H2.1, H3.1, H4.1; also elsewhere on the board

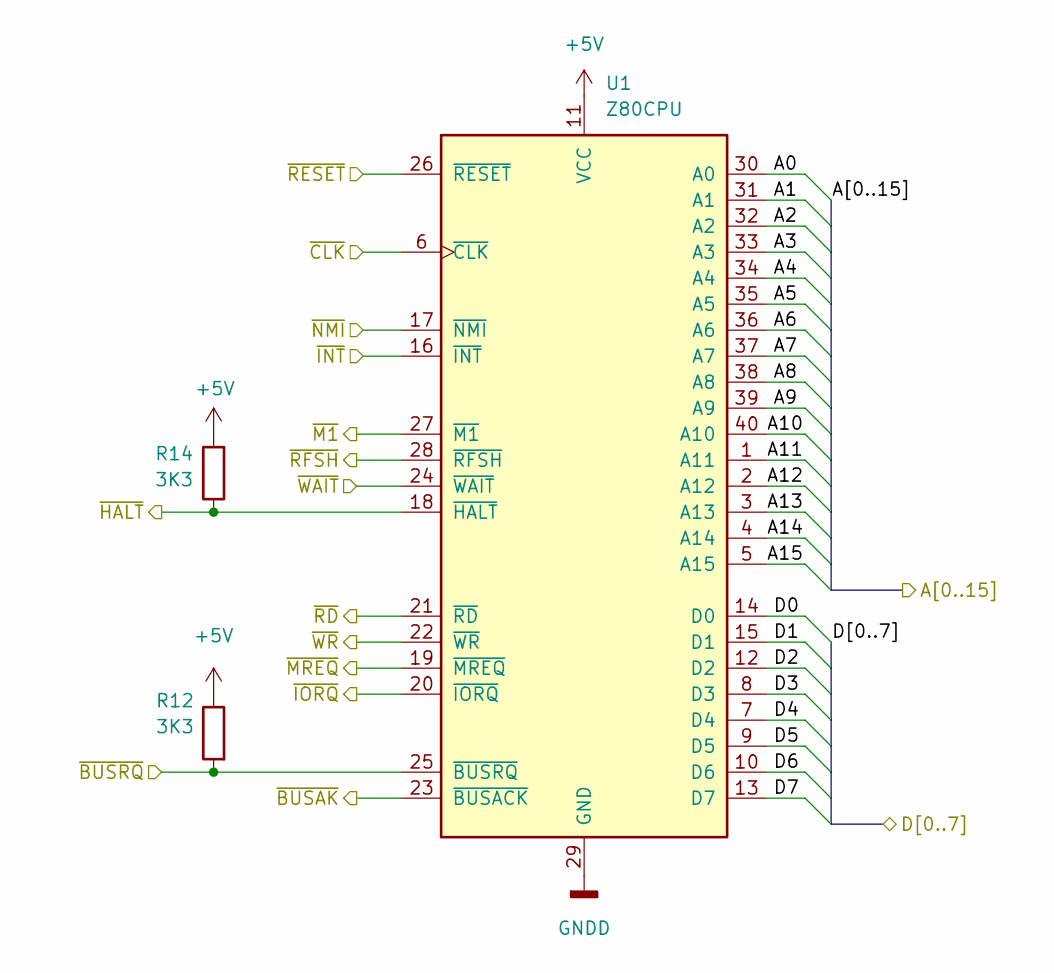
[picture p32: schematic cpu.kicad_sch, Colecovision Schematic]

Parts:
R12, R14: 3K3; R_Axial_DIN0207_L6.3mm_D2.5mm_P10.16mm_Horizontal
U1: Z80CPU; DIP-40_W15.24mm_LongPads

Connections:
+5V: R12.1, R14.2, U1.11 (VCC); also elsewhere on the board
/clock_reset_misc_logic/~CLK: U1.6 (~CLK); also elsewhere on the board
/clock_reset_misc_logic/~INT: U1.16 (~INT); also elsewhere on the board
/clock_reset_misc_logic/~M1: U1.27 (~M1); also elsewhere on the board
/clock_reset_misc_logic/~RESET: U1.26 (~RESET); also elsewhere on the board
/clock_reset_misc_logic/~RFSH: U1.28 (~RFSH); also elsewhere on the board
/clock_reset_misc_logic/~WAIT: U1.24 (~WAIT); also elsewhere on the board
/cpu/A0: U1.30 (A0); also elsewhere on the board
/cpu/A1: U1.31 (A1); also elsewhere on the board
/cpu/A2: U1.32 (A2); also elsewhere on the board
/cpu/A3: U1.33 (A3); also elsewhere on the board
/cpu/A4: U1.34 (A4); also elsewhere on the board
/cpu/A5: U1.35 (A5); also elsewhere on the board
/cpu/A6: U1.36 (A6); also elsewhere on the board
/cpu/A7: U1.37 (A7); also elsewhere on the board
/cpu/A8: U1.38 (A8); also elsewhere on the board
/cpu/A9: U1.39 (A9); also elsewhere on the board
/cpu/A10: U1.40 (A10); also elsewhere on the board
/cpu/A11: U1.1 (A11); also elsewhere on the board
/cpu/A12: U1.2 (A12); also elsewhere on the board
/cpu/A13: U1.3 (A13); also elsewhere on the board
/cpu/A14: U1.4 (A14); also elsewhere on the board
/cpu/A15: U1.5 (A15); also elsewhere on the board
/cpu/D0: U1.14 (D0); also elsewhere on the board
/cpu/D1: U1.15 (D1); also elsewhere on the board
/cpu/D2: U1.12 (D2); also elsewhere on the board
/cpu/D3: U1.8 (D3); also elsewhere on the board
/cpu/D4: U1.7 (D4); also elsewhere on the board
/cpu/D5: U1.9 (D5); also elsewhere on the board
/cpu/D6: U1.10 (D6); also elsewhere on the board
/cpu/D7: U1.13 (D7); also elsewhere on the board
/cpu/~BUSAK: U1.23 (~BUSACK); also elsewhere on the board
/cpu/~BUSRQ: R12.2, U1.25 (~BUSRQ); also elsewhere on the board
/cpu/~HALT: R14.1, U1.18 (~HALT); also elsewhere on the board
/cpu/~IORQ: U1.20 (~IORQ); also elsewhere on the board
/cpu/~MREQ: U1.19 (~MREQ); also elsewhere on the board
/cpu/~NMI: U1.17 (~NMI); also elsewhere on the board
/cpu/~RD: U1.21 (~RD); also elsewhere on the board
/cpu/~WR: U1.22 (~WR); also elsewhere on the board
GNDD: U1.29 (GND); also elsewhere on the board

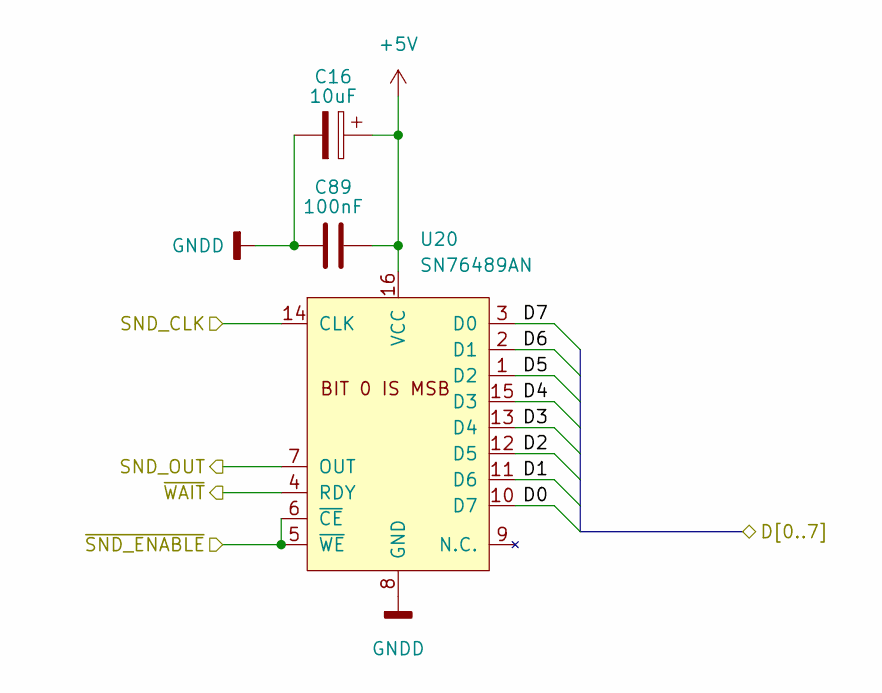
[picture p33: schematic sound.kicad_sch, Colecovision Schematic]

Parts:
C16: 10uF; CP_Radial_Tantal_D4.5mm_P5.00mm
C89: 100nF; C_Disc_D7.0mm_W2.5mm_P5.00mm
U20: SN76489AN; DIP-16_W7.62mm_LongPads

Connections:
+5V: C16.1, C89.1, U20.16 (VCC); also elsewhere on the board
/clock_reset_misc_logic/SND_CLK: U20.14 (CLK); also elsewhere on the board
/clock_reset_misc_logic/~WAIT: U20.4 (RDY); also elsewhere on the board
/cpu/D0: U20.10 (D7); also elsewhere on the board
/cpu/D1: U20.11 (D6); also elsewhere on the board
/cpu/D2: U20.12 (D5); also elsewhere on the board
/cpu/D3: U20.13 (D4); also elsewhere on the board
/cpu/D4: U20.15 (D3); also elsewhere on the board
/cpu/D5: U20.1 (D2); also elsewhere on the board
/cpu/D6: U20.2 (D1); also elsewhere on the board
/cpu/D7: U20.3 (D0); also elsewhere on the board
/decoder_logic/~SND_ENABLE: U20.5 (~WE), U20.6 (~CE); also elsewhere on the board
/io_ports/SND_OUT: U20.7 (OUT); also elsewhere on the board
GNDD: C16.2, C89.2, U20.8 (GND); also elsewhere on the board

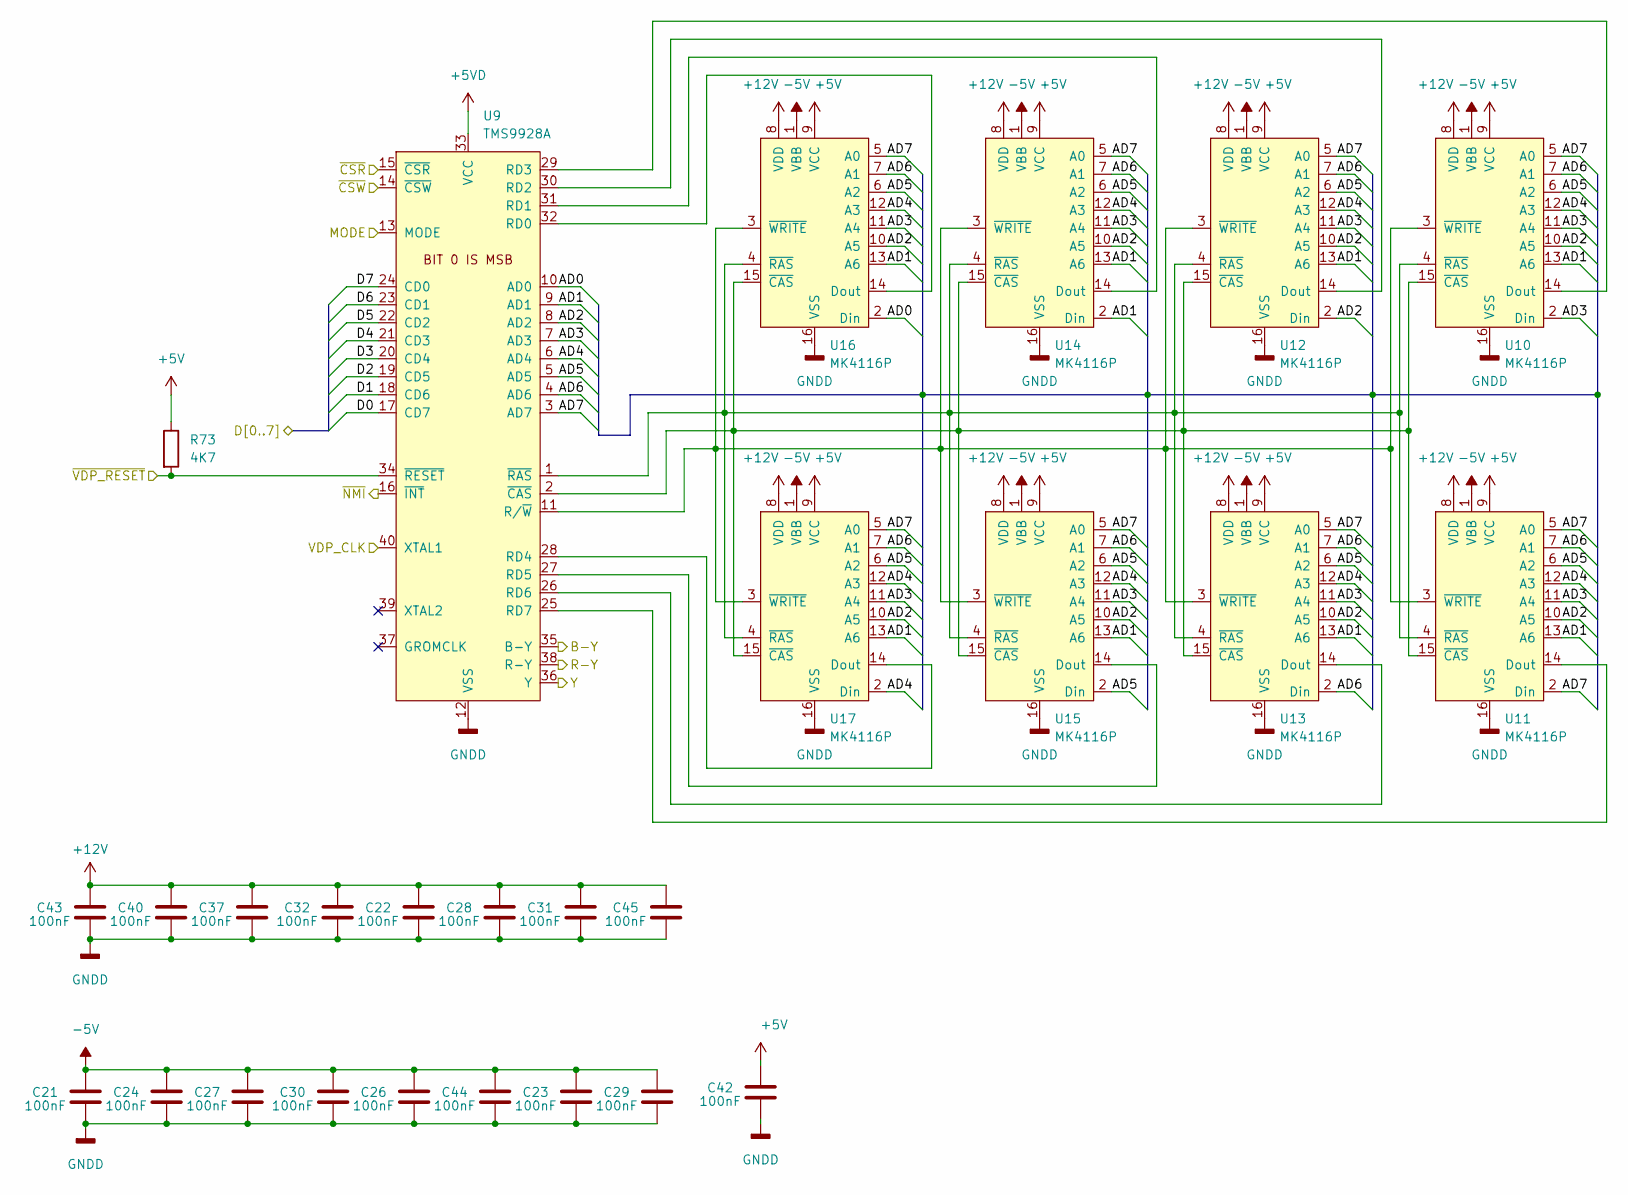
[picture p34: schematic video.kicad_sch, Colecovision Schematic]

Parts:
C21, C22, C23, C24, C26, C27, C28, C29, C30, C31, C32, C37, C40, C42, C43, C44, C45: 100nF; C_Disc_D7.0mm_W2.5mm_P5.00mm
R73: 4K7; R_Axial_DIN0207_L6.3mm_D2.5mm_P10.16mm_Horizontal
U9: TMS9928A; DIP-40_W15.24mm_LongPads
U10, U11, U12, U13, U14, U15, U16, U17: MK4116P; DIP-16_W7.62mm_LongPads

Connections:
+5V: C42.1, R73.1, U10.9 (VCC), U11.9 (VCC), U12.9 (VCC), U13.9 (VCC), U14.9 (VCC), U15.9 (VCC), U16.9 (VCC), U17.9 (VCC); also elsewhere on the board
+5VD: U9.33 (VCC); also elsewhere on the board
+12V: C22.1, C28.1, C31.1, C32.1, C37.1, C40.1, C43.1, C45.1, U10.8 (VDD), U11.8 (VDD), U12.8 (VDD), U13.8 (VDD), U14.8 (VDD), U15.8 (VDD), U16.8 (VDD), U17.8 (VDD); also elsewhere on the board
-5V: C21.1, C23.1, C24.1, C26.1, C27.1, C29.1, C30.1, C44.1, U10.1 (VBB), U11.1 (VBB), U12.1 (VBB), U13.1 (VBB), U14.1 (VBB), U15.1 (VBB), U16.1 (VBB), U17.1 (VBB); also elsewhere on the board
/clock_reset_misc_logic/VDP_CLK: U9.40 (XTAL1); also elsewhere on the board
/cpu/A0: U9.13 (MODE); also elsewhere on the board
/cpu/D0: U9.17 (CD7); also elsewhere on the board
/cpu/D1: U9.18 (CD6); also elsewhere on the board
/cpu/D2: U9.19 (CD5); also elsewhere on the board
/cpu/D3: U9.20 (CD4); also elsewhere on the board
/cpu/D4: U9.21 (CD3); also elsewhere on the board
/cpu/D5: U9.22 (CD2); also elsewhere on the board
/cpu/D6: U9.23 (CD1); also elsewhere on the board
/cpu/D7: U9.24 (CD0); also elsewhere on the board
/cpu/~NMI: U9.16 (~INT); also elsewhere on the board
/decoder_logic/~CSR: U9.15 (~CSR); also elsewhere on the board
/decoder_logic/~CSW: U9.14 (~CSW); also elsewhere on the board
/io_ports/~VDP_RESET: R73.2, U9.34 (~RESET); also elsewhere on the board
/rf_mod/B-Y: U9.35 (B-Y); also elsewhere on the board
/rf_mod/R-Y: U9.38 (R-Y); also elsewhere on the board
/rf_mod/Y: U9.36 (Y); also elsewhere on the board
/video/AD0: U9.10 (AD0), U16.2 (Din)
/video/AD1: U9.9 (AD1), U10.13 (A6), U11.13 (A6), U12.13 (A6), U13.13 (A6), U14.2 (Din), U14.13 (A6), U15.13 (A6), U16.13 (A6), U17.13 (A6)
/video/AD2: U9.8 (AD2), U10.10 (A5), U11.10 (A5), U12.2 (Din), U12.10 (A5), U13.10 (A5), U14.10 (A5), U15.10 (A5), U16.10 (A5), U17.10 (A5)
/video/AD3: U9.7 (AD3), U10.2 (Din), U10.11 (A4), U11.11 (A4), U12.11 (A4), U13.11 (A4), U14.11 (A4), U15.11 (A4), U16.11 (A4), U17.11 (A4)
/video/AD4: U9.6 (AD4), U10.12 (A3), U11.12 (A3), U12.12 (A3), U13.12 (A3), U14.12 (A3), U15.12 (A3), U16.12 (A3), U17.2 (Din), U17.12 (A3)
/video/AD5: U9.5 (AD5), U10.6 (A2), U11.6 (A2), U12.6 (A2), U13.6 (A2), U14.6 (A2), U15.2 (Din), U15.6 (A2), U16.6 (A2), U17.6 (A2)
/video/AD6: U9.4 (AD6), U10.7 (A1), U11.7 (A1), U12.7 (A1), U13.2 (Din), U13.7 (A1), U14.7 (A1), U15.7 (A1), U16.7 (A1), U17.7 (A1)
/video/AD7: U9.3 (AD7), U10.5 (A0), U11.2 (Din), U11.5 (A0), U12.5 (A0), U13.5 (A0), U14.5 (A0), U15.5 (A0), U16.5 (A0), U17.5 (A0)
GNDD: C21.2, C22.2, C23.2, C24.2, C26.2, C27.2, C28.2, C29.2, C30.2, C31.2, C32.2, C37.2, C40.2, C42.2, C43.2, C44.2, C45.2, U9.12 (VSS), U10.16 (VSS), U11.16 (VSS), U12.16 (VSS), U13.16 (VSS), U14.16 (VSS), U15.16 (VSS), U16.16 (VSS), U17.16 (VSS); also elsewhere on the board
unnamed: U9.11 (R/~W), U10.3 (~WRITE), U11.3 (~WRITE), U12.3 (~WRITE), U13.3 (~WRITE), U14.3 (~WRITE), U15.3 (~WRITE), U16.3 (~WRITE), U17.3 (~WRITE)
unnamed: U9.1 (~RAS), U10.4 (~RAS), U11.4 (~RAS), U12.4 (~RAS), U13.4 (~RAS), U14.4 (~RAS), U15.4 (~RAS), U16.4 (~RAS), U17.4 (~RAS)
unnamed: U9.29 (RD3), U10.14 (Dout)
unnamed: U9.2 (~CAS), U10.15 (~CAS), U11.15 (~CAS), U12.15 (~CAS), U13.15 (~CAS), U14.15 (~CAS), U15.15 (~CAS), U16.15 (~CAS), U17.15 (~CAS)
unnamed: U9.25 (RD7), U11.14 (Dout)
unnamed: U9.30 (RD2), U12.14 (Dout)
unnamed: U9.26 (RD6), U13.14 (Dout)
unnamed: U9.31 (RD1), U14.14 (Dout)
unnamed: U9.27 (RD5), U15.14 (Dout)
unnamed: U9.32 (RD0), U16.14 (Dout)
unnamed: U9.28 (RD4), U17.14 (Dout)

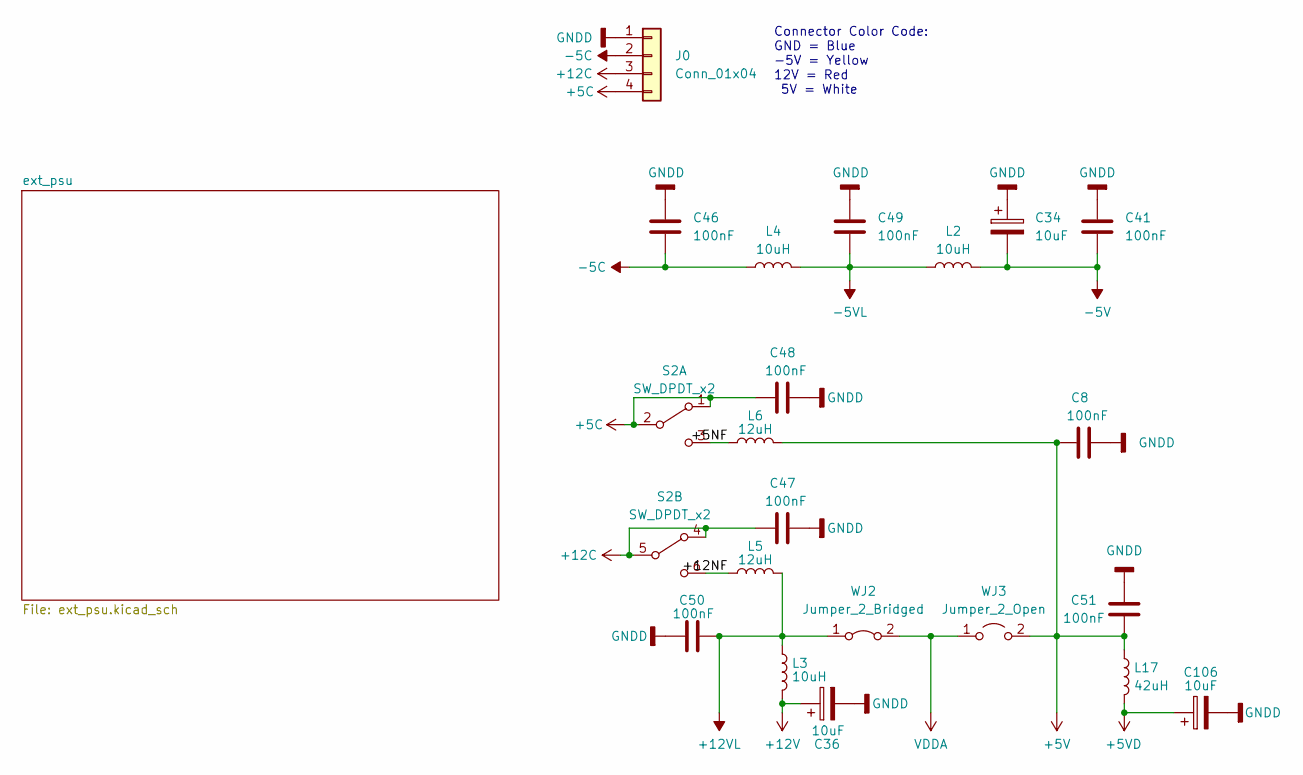
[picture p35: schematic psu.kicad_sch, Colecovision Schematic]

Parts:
C8, C41, C46, C47, C48, C49, C50, C51: 100nF; C_Disc_D7.0mm_W2.5mm_P5.00mm
C34, C36: 10uF; CP_Radial_Tantal_D4.5mm_P5.00mm
C106: 10uF; CP_Radial_Tantal_D4.5mm_P2.50mm
J0: Conn_01x04; Molex_KK-396_A-41791-0004_1x04_P3.96mm_Vertical
L2, L3, L4: 10uH; L_Axial_L11.0mm_D4.5mm_P7.62mm_Vertical_Fastron_MECC
L5, L6: 12uH; L_Axial_L12.8mm_D5.8mm_P25.40mm_Horizontal_Fastron_HBCC
L17: 42uH; L_Axial_L11.0mm_D4.5mm_P7.62mm_Vertical_Fastron_MECC
S2: SW_DPDT_x2; DPDT_GF-626-0061
WJ2: Jumper_2_Bridged; R_Axial_DIN0207_L6.3mm_D2.5mm_P15.24mm_Horizontal
WJ3: Jumper_2_Open; R_Axial_DIN0207_L6.3mm_D2.5mm_P15.24mm_Horizontal

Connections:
+5C: C48.2, J0.4, S2.1 (A), S2.2 (B)
+5V: C8.2, C51.1, L6.2, L17.1, WJ3.2 (B); also elsewhere on the board
+5VD: C106.1, L17.2; also elsewhere on the board
+12C: C47.2, J0.3, S2.4 (A), S2.5 (B)
+12V: C36.1, L3.2; also elsewhere on the board
+12VL: C50.2, L3.1, L5.2, WJ2.1 (A); also elsewhere on the board
-5C: C46.2, J0.2, L4.1
-5V: C34.2, C41.2, L2.2; also elsewhere on the board
-5VL: C49.2, L2.1, L4.2; also elsewhere on the board
/psu/+5NF: L6.1, S2.3 (C)
/psu/+12NF: L5.1, S2.6 (C)
GNDD: C8.1, C34.1, C36.2, C41.1, C46.1, C47.1, C48.1, C49.1, C50.1, C51.2, C106.2, J0.1; also elsewhere on the board
VDDA: WJ2.2 (B), WJ3.1 (A); also elsewhere on the board

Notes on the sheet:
Connector Color Code: GND = Blue -5V = Yellow 12V = Red 5V = White

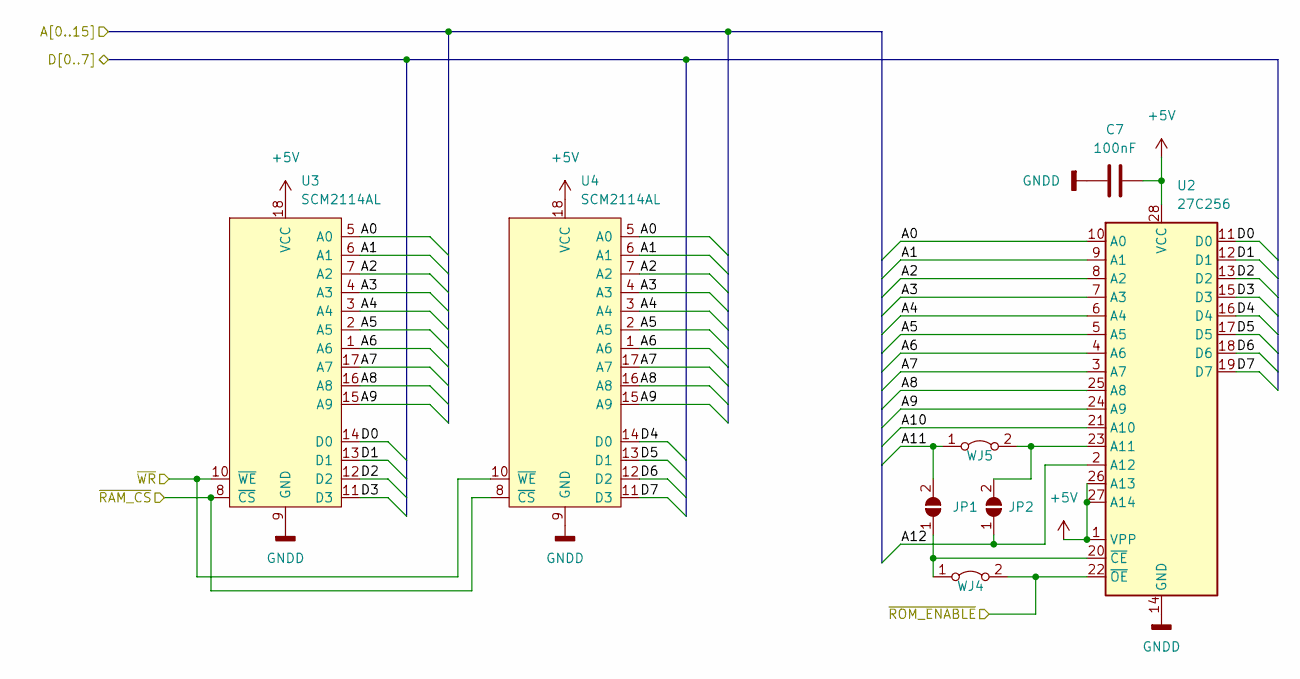
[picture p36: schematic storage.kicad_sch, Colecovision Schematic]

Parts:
C7: 100nF; C_Disc_D7.0mm_W2.5mm_P5.00mm
JP1, JP2: SolderJumper_2_Open; SolderJumper-2_P1.3mm_Open_Pad1.0x1.5mm
U2: 27C256; DIP-28_W15.24mm
U3, U4: SCM2114AL; DIP-18_W7.62mm_LongPads
WJ4, WJ5: Jumper_2_Bridged_32K_ROM; R_Axial_DIN0207_L6.3mm_D2.5mm_P15.24mm_Horizontal

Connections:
+5V: C7.1, U2.1 (VPP), U2.26 (A13), U2.27 (A14), U2.28 (VCC), U3.18 (VCC), U4.18 (VCC); also elsewhere on the board
/cpu/A0: U2.10 (A0), U3.5 (A0), U4.5 (A0); also elsewhere on the board
/cpu/A1: U2.9 (A1), U3.6 (A1), U4.6 (A1); also elsewhere on the board
/cpu/A2: U2.8 (A2), U3.7 (A2), U4.7 (A2); also elsewhere on the board
/cpu/A3: U2.7 (A3), U3.4 (A3), U4.4 (A3); also elsewhere on the board
/cpu/A4: U2.6 (A4), U3.3 (A4), U4.3 (A4); also elsewhere on the board
/cpu/A5: U2.5 (A5), U3.2 (A5), U4.2 (A5); also elsewhere on the board
/cpu/A6: U2.4 (A6), U3.1 (A6), U4.1 (A6); also elsewhere on the board
/cpu/A7: U2.3 (A7), U3.17 (A7), U4.17 (A7); also elsewhere on the board
/cpu/A8: U2.25 (A8), U3.16 (A8), U4.16 (A8); also elsewhere on the board
/cpu/A9: U2.24 (A9), U3.15 (A9), U4.15 (A9); also elsewhere on the board
/cpu/A10: U2.21 (A10); also elsewhere on the board
/cpu/A11: JP1.2 (B), WJ5.1 (A); also elsewhere on the board
/cpu/A12: JP2.1 (A), U2.2 (A12); also elsewhere on the board
/cpu/D0: U2.11 (D0), U3.14 (D0); also elsewhere on the board
/cpu/D1: U2.12 (D1), U3.13 (D1); also elsewhere on the board
/cpu/D2: U2.13 (D2), U3.12 (D2); also elsewhere on the board
/cpu/D3: U2.15 (D3), U3.11 (D3); also elsewhere on the board
/cpu/D4: U2.16 (D4), U4.14 (D0); also elsewhere on the board
/cpu/D5: U2.17 (D5), U4.13 (D1); also elsewhere on the board
/cpu/D6: U2.18 (D6), U4.12 (D2); also elsewhere on the board
/cpu/D7: U2.19 (D7), U4.11 (D3); also elsewhere on the board
/cpu/~WR: U3.10 (~WE), U4.10 (~WE); also elsewhere on the board
/decoder_logic/~RAM_CS: U3.8 (~CS), U4.8 (~CS); also elsewhere on the board
/decoder_logic/~ROM_ENABLE: U2.22 (~OE), WJ4.2 (B); also elsewhere on the board
GNDD: C7.2, U2.14 (GND), U3.9 (GND), U4.9 (GND); also elsewhere on the board
unnamed: JP1.1 (A), U2.20 (~CE), WJ4.1 (A)
unnamed: JP2.2 (B), U2.23 (A11), WJ5.2 (B)

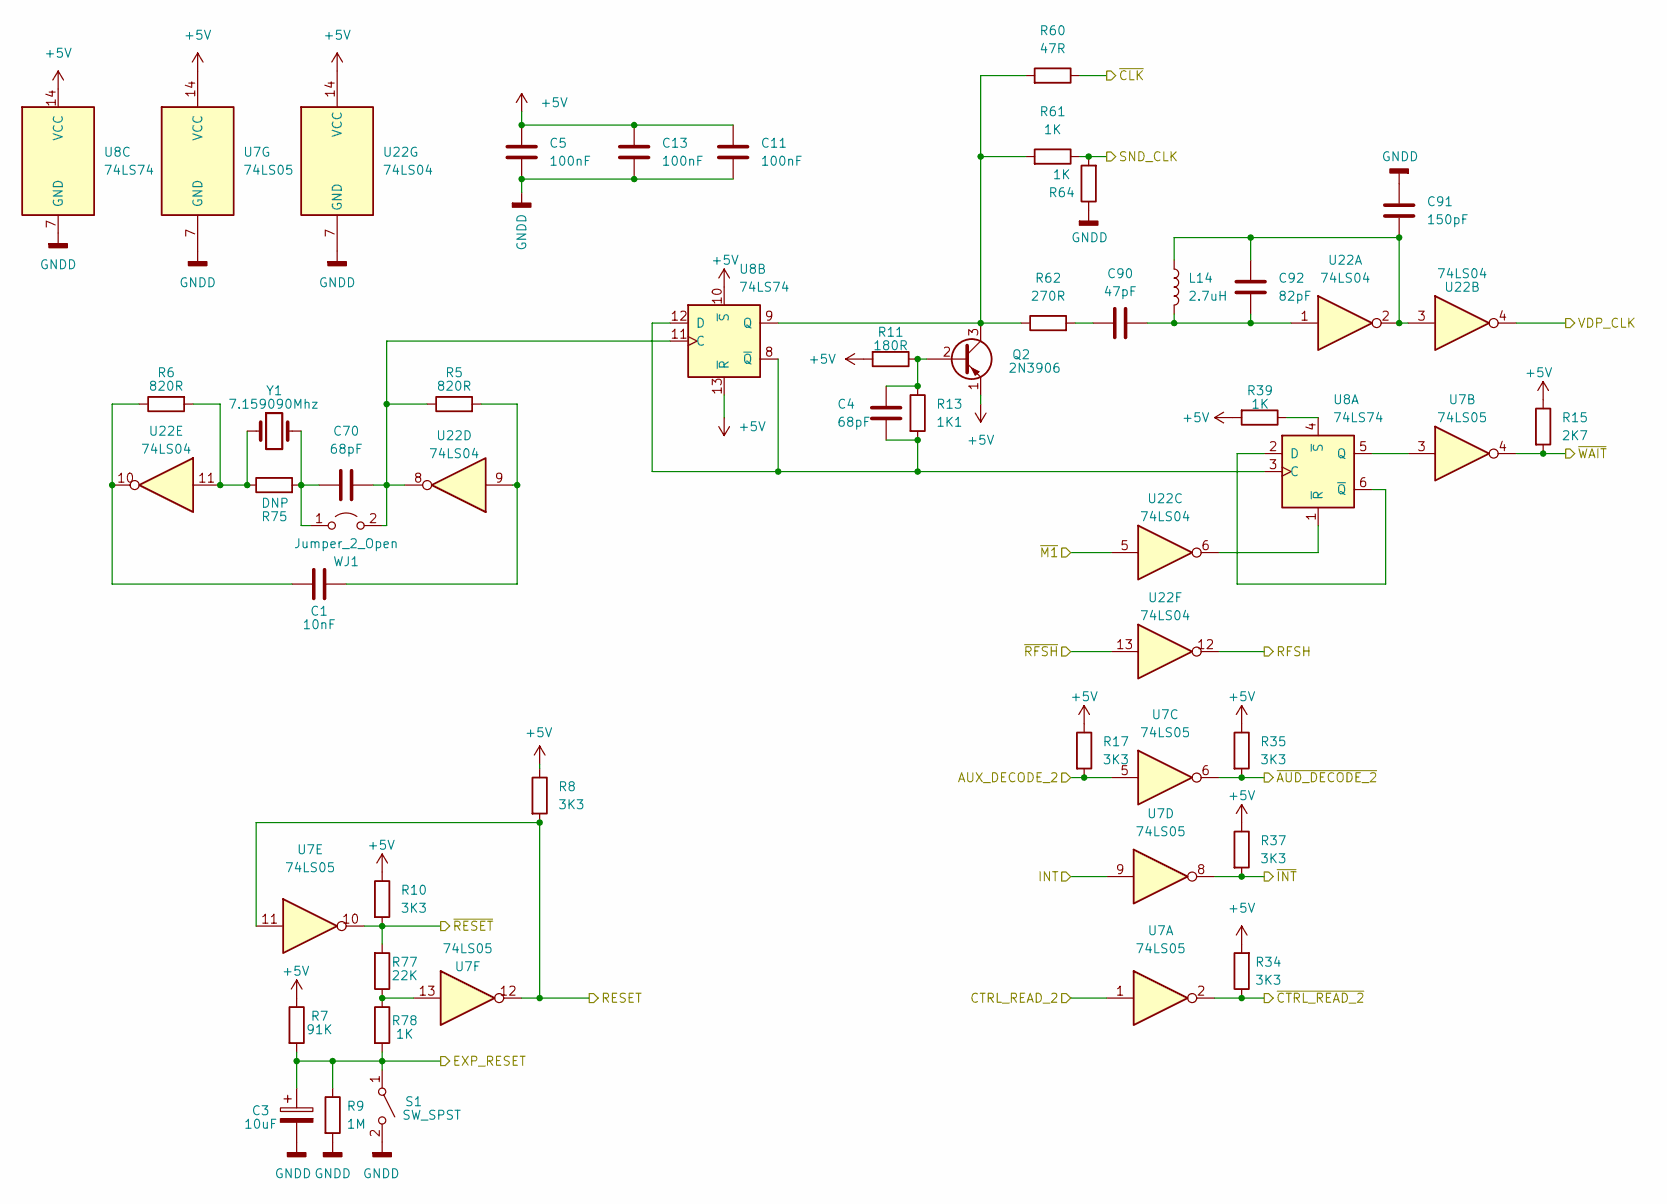
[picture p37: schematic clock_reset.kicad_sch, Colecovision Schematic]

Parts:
C1: 10nF; C_Disc_D7.0mm_W2.5mm_P5.00mm
C3: 10uF; CP_Radial_Tantal_D4.5mm_P5.00mm
C4, C70: 68pF; C_Disc_D7.0mm_W2.5mm_P5.00mm
C5, C11, C13: 100nF; C_Disc_D7.0mm_W2.5mm_P5.00mm
C90: 47pF; C_Disc_D7.0mm_W2.5mm_P5.00mm
C91: 150pF; C_Disc_D7.0mm_W2.5mm_P5.00mm
C92: 82pF; C_Disc_D7.0mm_W2.5mm_P5.00mm
L14: 2.7uH; L_Axial_L11.0mm_D4.5mm_P7.62mm_Vertical_Fastron_MECC
Q2: 2N3906; TO-92_Wide
R5, R6: 820R; R_Axial_DIN0207_L6.3mm_D2.5mm_P10.16mm_Horizontal
R7: 91K; R_Axial_DIN0207_L6.3mm_D2.5mm_P10.16mm_Horizontal
R8, R10, R17, R34, R35, R37: 3K3; R_Axial_DIN0207_L6.3mm_D2.5mm_P10.16mm_Horizontal
R9: 1M; R_Axial_DIN0207_L6.3mm_D2.5mm_P10.16mm_Horizontal
R11: 180R; R_Axial_DIN0207_L6.3mm_D2.5mm_P10.16mm_Horizontal
R13: 1K1; R_Axial_DIN0207_L6.3mm_D2.5mm_P10.16mm_Horizontal
R15: 2K7; R_Axial_DIN0207_L6.3mm_D2.5mm_P10.16mm_Horizontal
R39, R61, R64, R78: 1K; R_Axial_DIN0207_L6.3mm_D2.5mm_P10.16mm_Horizontal
R60: 47R; R_Axial_DIN0207_L6.3mm_D2.5mm_P10.16mm_Horizontal
R62: 270R; R_Axial_DIN0207_L6.3mm_D2.5mm_P10.16mm_Horizontal
R75: DNP; R_Axial_DIN0207_L6.3mm_D2.5mm_P10.16mm_Horizontal
R77: 22K; R_Axial_DIN0207_L6.3mm_D2.5mm_P10.16mm_Horizontal
S1: SW_SPST; Coleco_RST
U7: 74LS05; DIP-14_W7.62mm_LongPads
U8: 74LS74; DIP-14_W7.62mm_LongPads
U22: 74LS04; DIP-14_W7.62mm_LongPads
WJ1: Jumper_2_Open; R_Axial_DIN0207_L6.3mm_D2.5mm_P15.24mm_Horizontal
Y1: 7.159090Mhz; Crystal_HC49-U_Vertical

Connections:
+5V: C5.2, C11.2, C13.2, Q2.1 (E), R7.1, R8.1, R10.1, R11.2, R15.1, R17.1, R34.2, R35.1, R37.1, R39.2, U7.14 (VCC), U8.10 (~S), U8.13 (~R), U8.14 (VCC), U22.14 (VCC); also elsewhere on the board
/clock_reset_misc_logic/AUX_DECODE_2: R17.2, U7.5; also elsewhere on the board
/clock_reset_misc_logic/EXP_RESET: C3.1, R7.2, R9.1, R78.2, S1.1 (A); also elsewhere on the board
/clock_reset_misc_logic/INT: U7.9; also elsewhere on the board
/clock_reset_misc_logic/RESET: R8.2, U7.11, U7.12; also elsewhere on the board
/clock_reset_misc_logic/RFSH: U22.12; also elsewhere on the board
/clock_reset_misc_logic/SND_CLK: R61.1, R64.2; also elsewhere on the board
/clock_reset_misc_logic/VDP_CLK: U22.4; also elsewhere on the board
/clock_reset_misc_logic/~AUD_DECODE_2: R35.2, U7.6; also elsewhere on the board
/clock_reset_misc_logic/~CLK: R60.1; also elsewhere on the board
/clock_reset_misc_logic/~CTRL_READ_2: R34.1, U7.2; also elsewhere on the board
/clock_reset_misc_logic/~INT: R37.2, U7.8; also elsewhere on the board
/clock_reset_misc_logic/~M1: U22.5; also elsewhere on the board
/clock_reset_misc_logic/~RESET: R10.2, R77.2, U7.10; also elsewhere on the board
/clock_reset_misc_logic/~RFSH: U22.13; also elsewhere on the board
/clock_reset_misc_logic/~WAIT: R15.2, U7.4; also elsewhere on the board
/cpu/A1: U7.1; also elsewhere on the board
GNDD: C3.2, C5.1, C11.1, C13.1, C91.1, R9.2, R64.1, S1.2 (B), U7.7 (GND), U8.7 (GND), U22.7 (GND); also elsewhere on the board
unnamed: C1.1, R6.1, U22.10
unnamed: C1.2, R5.2, U22.9
unnamed: C4.1, Q2.2 (B), R11.1, R13.1
unnamed: C4.2, R13.2, U8.3 (C), U8.8 (~Q), U8.12 (D)
unnamed: C70.1, R5.1, U8.11 (C), U22.8, WJ1.2 (B)
unnamed: C70.2, R75.2, WJ1.1 (A), Y1.2
unnamed: C90.1, R62.2
unnamed: C90.2, C92.2, L14.2, U22.1
unnamed: C91.2, C92.1, L14.1, U22.2, U22.3
unnamed: Q2.3 (C), R60.2, R61.2, R62.1, U8.9 (Q)
unnamed: R6.2, R75.1, U22.11, Y1.1
unnamed: R39.1, U8.4 (~S)
unnamed: R77.1, R78.1, U7.13
unnamed: U7.3, U8.5 (Q)
unnamed: U8.2 (D), U8.6 (~Q)
unnamed: U8.1 (~R), U22.6

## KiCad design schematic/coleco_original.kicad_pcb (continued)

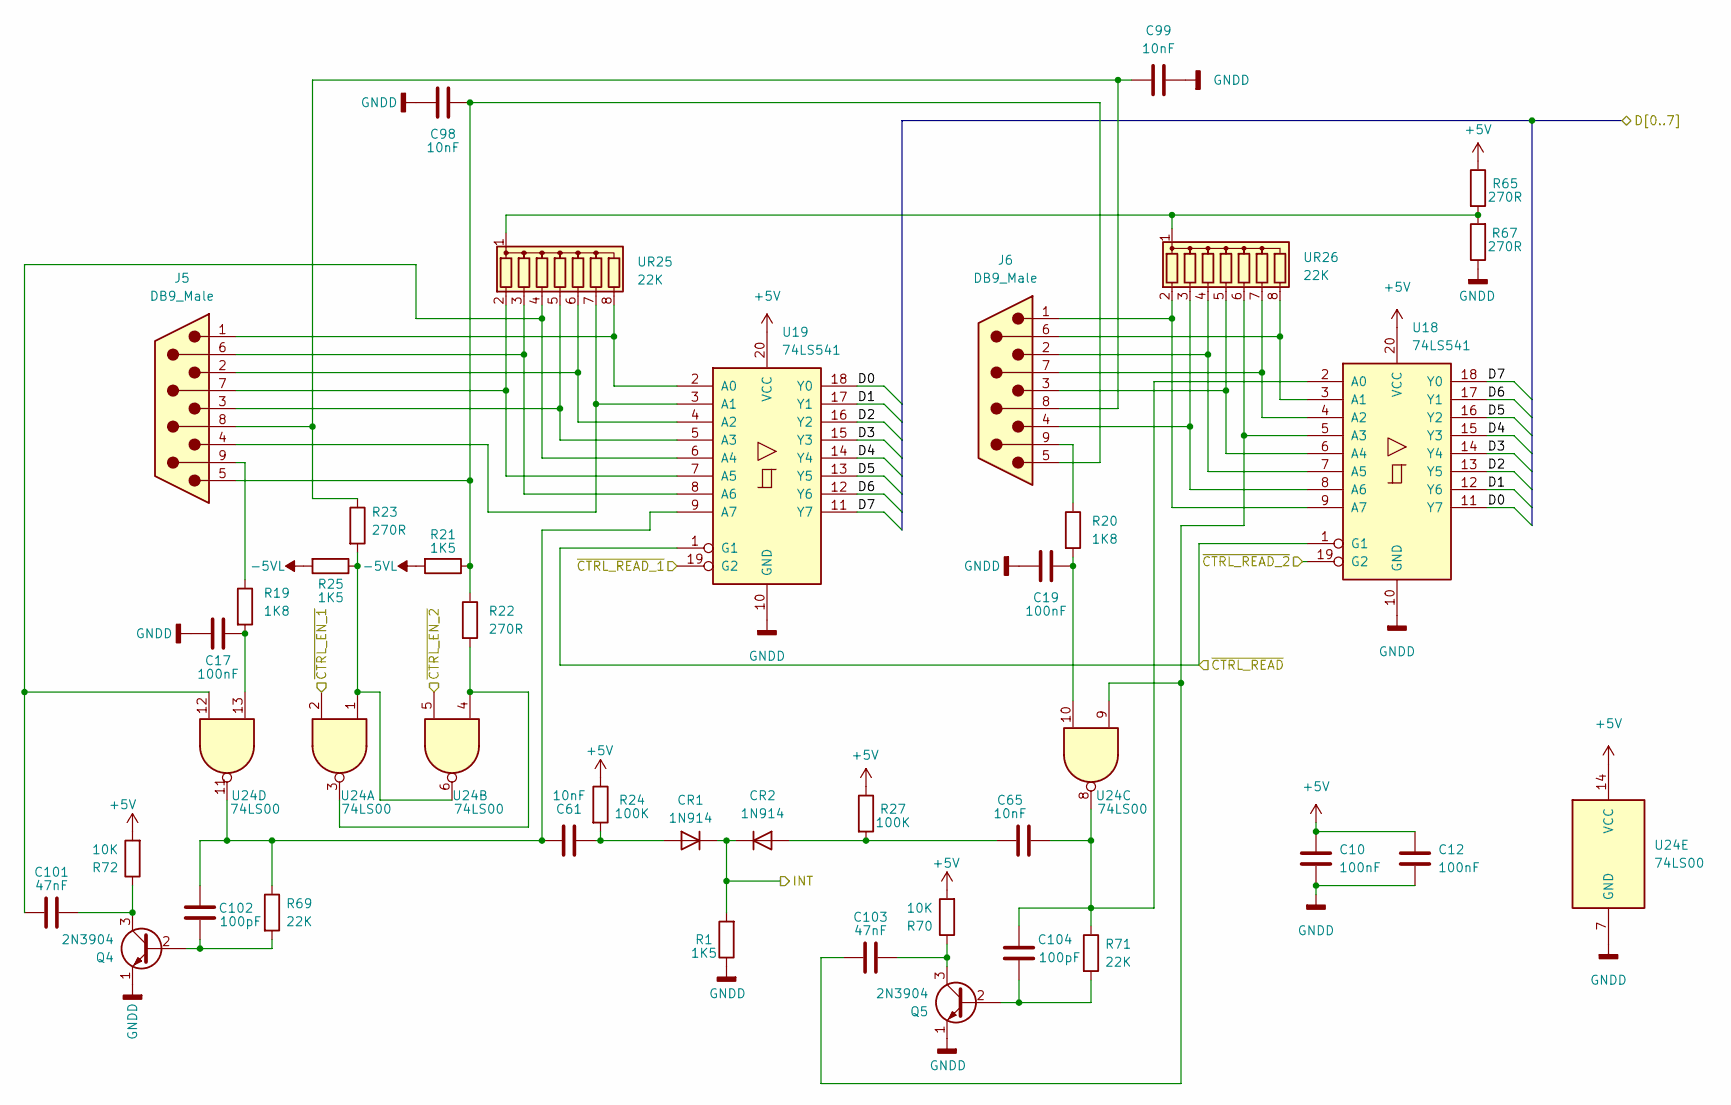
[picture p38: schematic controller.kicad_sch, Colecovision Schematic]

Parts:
C10, C12, C17, C19: 100nF; C_Disc_D7.0mm_W2.5mm_P5.00mm
C61, C65, C98, C99: 10nF; C_Disc_D7.0mm_W2.5mm_P5.00mm
C101, C103: 47nF; C_Disc_D7.0mm_W2.5mm_P5.00mm
C102, C104: 100pF; C_Disc_D7.0mm_W2.5mm_P5.00mm
CR1, CR2: 1N914; D_DO-35_SOD27_P10.16mm_Horizontal
J5, J6: DB9_Male; DSUB-9_Male_Horizontal_P2.77x2.54mm_EdgePinOffset9.40mm
Q4, Q5: 2N3904; TO-92_Wide
R1, R21, R25: 1K5; R_Axial_DIN0207_L6.3mm_D2.5mm_P10.16mm_Horizontal
R19, R20: 1K8; R_Axial_DIN0207_L6.3mm_D2.5mm_P10.16mm_Horizontal
R22, R23, R65, R67: 270R; R_Axial_DIN0207_L6.3mm_D2.5mm_P10.16mm_Horizontal
R24, R27: 100K; R_Axial_DIN0207_L6.3mm_D2.5mm_P10.16mm_Horizontal
R69, R71: 22K; R_Axial_DIN0207_L6.3mm_D2.5mm_P10.16mm_Horizontal
R70, R72: 10K; R_Axial_DIN0207_L6.3mm_D2.5mm_P10.16mm_Horizontal
U18, U19: 74LS541; DIP-20_W7.62mm_LongPads
U24: 74LS00; DIP-14_W7.62mm_LongPads
UR25, UR26: 22K; R_Array_SIP8

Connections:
+5V: C10.1, C12.1, R24.1, R27.1, R65.1, R70.2, R72.2, U18.20 (VCC), U19.20 (VCC), U24.14 (VCC); also elsewhere on the board
-5VL: R21.2, R25.2; also elsewhere on the board
/clock_reset_misc_logic/INT: CR1.1 (K), CR2.1 (K), R1.2; also elsewhere on the board
/clock_reset_misc_logic/~CTRL_READ_2: U18.19 (G2); also elsewhere on the board
/controller/~CTRL_EN_1: U24.2; also elsewhere on the board
/controller/~CTRL_EN_2: U24.5; also elsewhere on the board
/controller/~CTRL_READ: U18.1 (G1), U19.1 (G1); also elsewhere on the board
/cpu/A1: U19.19 (G2); also elsewhere on the board
/cpu/D0: U18.11 (Y7), U19.18 (Y0); also elsewhere on the board
/cpu/D1: U18.12 (Y6), U19.17 (Y1); also elsewhere on the board
/cpu/D2: U18.13 (Y5), U19.16 (Y2); also elsewhere on the board
/cpu/D3: U18.14 (Y4), U19.15 (Y3); also elsewhere on the board
/cpu/D4: U18.15 (Y3), U19.14 (Y4); also elsewhere on the board
/cpu/D5: U18.16 (Y2), U19.13 (Y5); also elsewhere on the board
/cpu/D6: U18.17 (Y1), U19.12 (Y6); also elsewhere on the board
/cpu/D7: U18.18 (Y0), U19.11 (Y7); also elsewhere on the board
GNDD: C10.2, C12.2, C17.1, C19.1, C98.1, C99.2, Q4.1 (E), Q5.1 (E), R1.1, R67.1, U18.10 (GND), U19.10 (GND), U24.7 (GND); also elsewhere on the board
unnamed: C17.2, R19.2, U24.13
unnamed: C19.2, R20.2, U24.10
unnamed: C61.1, CR1.2 (A), R24.2
unnamed: C65.1, CR2.2 (A), R27.2
unnamed: C98.2, J5.5, J6.5, R21.1, R22.1
unnamed: C99.1, J5.8, J6.8, R23.1
unnamed: C101.1, Q4.3 (C), R72.1
unnamed: C101.2, U19.6 (A4), U24.12, UR25.4 (R3)
unnamed: C102.1, Q4.2 (B), R69.2
unnamed: C61.2, C102.2, R69.1, U19.9 (A7), U24.11
unnamed: C103.1, Q5.3 (C), R70.1
unnamed: C103.2, U18.5 (A3), U24.9, UR26.6 (R5)
unnamed: C104.1, Q5.2 (B), R71.2
unnamed: C65.2, C104.2, R71.1, U18.2 (A0), U24.8
unnamed: J5.1, U19.2 (A0), UR25.8 (R7)
unnamed: J5.2, U19.4 (A2), UR25.6 (R5)
unnamed: J5.3, U19.5 (A3), UR25.5 (R4)
unnamed: J5.4, U19.3 (A1), UR25.7 (R6)
unnamed: J5.6, U19.8 (A6), UR25.3 (R2)
unnamed: J5.7, U19.7 (A5), UR25.2 (R1)
unnamed: J5.9, R19.1
unnamed: J6.1, U18.9 (A7), UR26.2 (R1)
unnamed: J6.2, U18.7 (A5), UR26.4 (R3)
unnamed: J6.3, U18.6 (A4), UR26.5 (R4)
unnamed: J6.4, U18.8 (A6), UR26.3 (R2)
unnamed: J6.6, U18.3 (A1), UR26.8 (R7)
unnamed: J6.7, U18.4 (A2), UR26.7 (R6)
unnamed: J6.9, R20.1
unnamed: R22.2, U24.3, U24.4
unnamed: R23.2, R25.1, U24.1, U24.6
unnamed: R65.2, R67.2, UR25.1 (common), UR26.1 (common)

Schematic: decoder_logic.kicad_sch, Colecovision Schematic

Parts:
C2: 100nF; C_Disc_D7.0mm_W2.5mm_P5.00mm
U5, U6: 74LS138; DIP-16_W7.62mm_LongPads

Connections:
+5V: C2.1, U5.16 (VCC); also elsewhere on the board
+5VD: U6.16 (VCC); also elsewhere on the board
/clock_reset_misc_logic/RFSH: U5.5 (E2); also elsewhere on the board
/clock_reset_misc_logic/~AUD_DECODE_2: U6.5 (E2); also elsewhere on the board
/controller/~CTRL_EN_1: U6.11 (O4); also elsewhere on the board
/controller/~CTRL_EN_2: U6.15 (O0); also elsewhere on the board
/controller/~CTRL_READ: U6.7 (O7); also elsewhere on the board
/cpu/A5: U6.2 (A1); also elsewhere on the board
/cpu/A6: U6.3 (A2); also elsewhere on the board
/cpu/A7: U6.6 (E3); also elsewhere on the board
/cpu/A13: U5.1 (A0); also elsewhere on the board
/cpu/A14: U5.2 (A1); also elsewhere on the board
/cpu/A15: U5.3 (A2); also elsewhere on the board
/cpu/~IORQ: U6.4 (E1); also elsewhere on the board
/cpu/~MREQ: U5.4 (E1); also elsewhere on the board
/cpu/~WR: U6.1 (A0); also elsewhere on the board
/decoder_logic/AUX_DECODE_1: U5.6 (E3); also elsewhere on the board
/decoder_logic/~CSR: U6.12 (O3); also elsewhere on the board
/decoder_logic/~CSW: U6.13 (O2); also elsewhere on the board
/decoder_logic/~CS_h2000: U5.14 (O1); also elsewhere on the board
/decoder_logic/~CS_h4000: U5.13 (O2); also elsewhere on the board
/decoder_logic/~CS_h8000: U5.11 (O4); also elsewhere on the board
/decoder_logic/~CS_hA000: U5.10 (O5); also elsewhere on the board
/decoder_logic/~CS_hC000: U5.9 (O6); also elsewhere on the board
/decoder_logic/~CS_hE000: U5.7 (O7); also elsewhere on the board
/decoder_logic/~RAM_CS: U5.12 (O3); also elsewhere on the board
/decoder_logic/~ROM_ENABLE: U5.15 (O0); also elsewhere on the board
/decoder_logic/~SND_ENABLE: U6.9 (O6); also elsewhere on the board
GNDD: C2.2, U5.8 (GND), U6.8 (GND); also elsewhere on the board

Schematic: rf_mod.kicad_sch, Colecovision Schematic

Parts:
C57, C78: 10nF; C_Disc_D7.0mm_W2.5mm_P5.00mm
C60, C69: 47nF; C_Disc_D7.0mm_W2.5mm_P5.00mm
C62, C63: 470pF; C_Disc_D7.0mm_W2.5mm_P5.00mm
C64: 120pF; C_Disc_D7.0mm_W2.5mm_P5.00mm
C66, C67, C88, C100: 100nF; C_Disc_D7.0mm_W2.5mm_P5.00mm
C68, C87: 10uF; CP_Radial_Tantal_D4.5mm_P5.00mm
J4A1: Conn_01x08; PinHeader_1x08_P2.54mm_Vertical
L7, L8: 120uH; L_Axial_L11.0mm_D4.5mm_P7.62mm_Vertical_Fastron_MECC
L9, L15: 42uH; L_Axial_L11.0mm_D4.5mm_P7.62mm_Vertical_Fastron_MECC
L10: 10uH; L_Axial_L11.0mm_D4.5mm_P7.62mm_Vertical_Fastron_MECC
Q3, Q6: 2N3906; TO-92_Wide
R18, R55, R76: 1K8; R_Axial_DIN0207_L6.3mm_D2.5mm_P10.16mm_Horizontal
R40, R41, R42: 390R; R_Axial_DIN0207_L6.3mm_D2.5mm_P10.16mm_Horizontal
R43, R49: 10K; R_Axial_DIN0207_L6.3mm_D2.5mm_P10.16mm_Horizontal
R48: 470K; R_Axial_DIN0207_L6.3mm_D2.5mm_P10.16mm_Horizontal
R79: 1K5; R_Axial_DIN0207_L6.3mm_D2.5mm_P10.16mm_Horizontal
U23: 4066; DIP-14_W7.62mm_LongPads

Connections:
+12VL: Q3.1 (E), R76.2, R79.1, U23.14 (VDD); also elsewhere on the board
/clock_reset_misc_logic/SND_CLK: L15.2; also elsewhere on the board
/io_ports/EXT_SOUND: C88.1; also elsewhere on the board
/io_ports/EXT_VIDEO: U23.9; also elsewhere on the board
/io_ports/EXT_VIDEO_SEL: R43.2, R48.2, U23.6; also elsewhere on the board
/io_ports/SND_OUT: R18.2; also elsewhere on the board
/rf_mod/B-Y: L8.2; also elsewhere on the board
/rf_mod/R-Y: L7.2; also elsewhere on the board
/rf_mod/Y: L9.1; also elsewhere on the board
/rf_mod/sub_rf_mod/2: C100.2, J4A1.2; also elsewhere on the board
/rf_mod/sub_rf_mod/3: C66.1, J4A1.3, U23.4; also elsewhere on the board
/rf_mod/sub_rf_mod/5: C87.1, J4A1.5, U23.2, U23.3, U23.10; also elsewhere on the board
/rf_mod/sub_rf_mod/6: J4A1.6, R55.1, U23.8; also elsewhere on the board
/rf_mod/sub_rf_mod/7: C67.2, J4A1.7, U23.1; also elsewhere on the board
/rf_mod/sub_rf_mod/8: C78.1, J4A1.8; also elsewhere on the board
GNDD: C57.2, C60.2, C62.2, C63.2, C64.2, C87.2, J4A1.1, Q6.3 (C), R40.2, R41.2, R42.2, R43.1, R49.2, U23.7 (VSS); also elsewhere on the board
unnamed: C62.1, C66.2, L7.1, R40.1
unnamed: C63.1, C67.1, L8.1, R41.1
unnamed: C64.1, L9.2, Q6.2 (B), R42.1
unnamed: C68.1, C69.2, R55.2, R79.2, U23.11
unnamed: C68.2, Q6.1 (E), R76.1
unnamed: C69.1, Q3.2 (B), R48.1
unnamed: C78.2, L15.1
unnamed: C88.2, C100.1, R18.1
unnamed: Q3.3 (C), R49.1, U23.5, U23.12, U23.13
VDDA: C60.1, L10.2; also elsewhere on the board
VDDF: C57.1, J4A1.4, L10.1; also elsewhere on the board

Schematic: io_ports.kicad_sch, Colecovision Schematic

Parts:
C9: 100nF; C_Disc_D7.0mm_W2.5mm_P5.00mm
J1: Cartridge Port; 55308412_coleco
J2: Expansion Port; Colecovision_Expansion
R16: 3K3; R_Axial_DIN0207_L6.3mm_D2.5mm_P10.16mm_Horizontal
R26: 470R; R_Axial_DIN0207_L6.3mm_D2.5mm_P10.16mm_Horizontal

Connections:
+5V: C9.1, J1.30, J2.58, J2.59, R16.1; also elsewhere on the board
+12VL: J2.57; also elsewhere on the board
-5VL: J2.60; also elsewhere on the board
/clock_reset_misc_logic/AUX_DECODE_2: J2.30; also elsewhere on the board
/clock_reset_misc_logic/EXP_RESET: J2.34; also elsewhere on the board
/clock_reset_misc_logic/INT: J2.10; also elsewhere on the board
/clock_reset_misc_logic/RESET: J2.36; also elsewhere on the board
/clock_reset_misc_logic/SND_CLK: J2.35; also elsewhere on the board
/clock_reset_misc_logic/~CLK: J2.45, R26.2; also elsewhere on the board
/clock_reset_misc_logic/~INT: J2.51; also elsewhere on the board
/clock_reset_misc_logic/~M1: J2.15; also elsewhere on the board
/clock_reset_misc_logic/~RESET: J2.13; also elsewhere on the board
/clock_reset_misc_logic/~RFSH: J2.49; also elsewhere on the board
/clock_reset_misc_logic/~WAIT: J2.50; also elsewhere on the board
/cpu/A0: J1.7, J2.47; also elsewhere on the board
/cpu/A1: J1.9, J2.18; also elsewhere on the board
/cpu/A2: J1.11, J2.20; also elsewhere on the board
/cpu/A3: J1.15, J2.44; also elsewhere on the board
/cpu/A4: J1.17, J2.21; also elsewhere on the board
/cpu/A5: J1.21, J2.23; also elsewhere on the board
/cpu/A6: J1.23, J2.24; also elsewhere on the board
/cpu/A7: J1.25, J2.25; also elsewhere on the board
/cpu/A8: J1.28, J2.26; also elsewhere on the board
/cpu/A9: J1.26, J2.27; also elsewhere on the board
/cpu/A10: J1.16, J2.28; also elsewhere on the board
/cpu/A11: J1.14, J2.37; also elsewhere on the board
/cpu/A12: J1.24, J2.38; also elsewhere on the board
/cpu/A13: J1.19, J2.22; also elsewhere on the board
/cpu/A14: J1.20, J2.4; also elsewhere on the board
/cpu/A15: J2.43; also elsewhere on the board
/cpu/D0: J1.5, J2.14; also elsewhere on the board
/cpu/D1: J1.3, J2.12; also elsewhere on the board
/cpu/D2: J1.1, J2.46; also elsewhere on the board
/cpu/D3: J1.4, J2.3; also elsewhere on the board
/cpu/D4: J1.6, J2.19; also elsewhere on the board
/cpu/D5: J1.8, J2.48; also elsewhere on the board
/cpu/D6: J1.10, J2.17; also elsewhere on the board
/cpu/D7: J1.12, J2.16; also elsewhere on the board
/cpu/~BUSAK: J2.52; also elsewhere on the board
/cpu/~BUSRQ: J2.11; also elsewhere on the board
/cpu/~HALT: J2.7; also elsewhere on the board
/cpu/~IORQ: J2.55; also elsewhere on the board
/cpu/~MREQ: J2.54; also elsewhere on the board
/cpu/~NMI: J2.9; also elsewhere on the board
/cpu/~RD: J2.53; also elsewhere on the board
/cpu/~WR: J2.8; also elsewhere on the board
/decoder_logic/AUX_DECODE_1: J2.29, R16.2; also elsewhere on the board
/decoder_logic/~CS_h2000: J2.6; also elsewhere on the board
/decoder_logic/~CS_h4000: J2.5; also elsewhere on the board
/decoder_logic/~CS_h8000: J1.18; also elsewhere on the board
/decoder_logic/~CS_hA000: J1.22; also elsewhere on the board
/decoder_logic/~CS_hC000: J1.2; also elsewhere on the board
/decoder_logic/~CS_hE000: J1.27; also elsewhere on the board
/io_ports/EXT_SOUND: J2.31; also elsewhere on the board
/io_ports/EXT_VIDEO: J2.33; also elsewhere on the board
/io_ports/EXT_VIDEO_SEL: J2.32; also elsewhere on the board
/io_ports/SND_OUT: J2.56; also elsewhere on the board
/io_ports/~VDP_RESET: J2.39; also elsewhere on the board
GND: J1.13; also elsewhere on the board
GNDD: C9.2, J1.29, J2.1, J2.2; also elsewhere on the board
unnamed: J2.40, R26.1

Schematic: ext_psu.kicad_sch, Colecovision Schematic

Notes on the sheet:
MEAN WELL 28.5 Watt PSU: GP25A13D-R1B GP25B13A-R1B

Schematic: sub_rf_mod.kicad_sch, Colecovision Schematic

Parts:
J4B1: Conn_01x08; PinHeader_1x08_P2.54mm_Vertical
RF_C1: 1nF; C_Disc_D7.0mm_W2.5mm_P5.00mm
RF_C2, RF_C10: 10pF; C_Disc_D7.0mm_W2.5mm_P5.00mm
RF_C3, RF_C8: 10nF; C_Disc_D7.0mm_W2.5mm_P5.00mm
RF_C4, RF_C5, RF_C7: 47pF; C_Disc_D7.0mm_W2.5mm_P5.00mm
RF_C6, RF_C9: 82pF; C_Disc_D7.0mm_W2.5mm_P5.00mm
RF_C11: 270pF; C_Disc_D7.0mm_W2.5mm_P5.00mm
RF_C12: 20pF; C_Disc_D7.0mm_W2.5mm_P5.00mm
RF_C13: 10uF; CP_Radial_D5.0mm_P2.00mm
RF_D1: 1N753; D_DO-35_SOD27_P10.16mm_Horizontal
RF_D2: BB329A; D_DO-35_SOD27_P10.16mm_Horizontal
RF_J1: RF_OUT; RCJ041
RF_JP1: Jumper_2_Bridged; R_Axial_DIN0207_L6.3mm_D2.5mm_P15.24mm_Horizontal
RF_L1, RF_L2: 1.4uH; L_Radial_D7.5mm_P5.00mm_Fastron_07P
RF_L3: 1.5uH; L_Radial_D7.5mm_P5.00mm_Fastron_07P
RF_R1, RF_R10: 39K; R_Axial_DIN0207_L6.3mm_D2.5mm_P7.62mm_Horizontal
RF_R2, RF_R3, RF_R4: 1K; R_Axial_DIN0207_L6.3mm_D2.5mm_P7.62mm_Horizontal
RF_R5, RF_R6: 270R; R_Axial_DIN0207_L6.3mm_D2.5mm_P7.62mm_Horizontal
RF_R7: 47R; R_Axial_DIN0207_L6.3mm_D2.5mm_P7.62mm_Horizontal
RF_R8: 82R; R_Axial_DIN0207_L6.3mm_D2.5mm_P7.62mm_Horizontal
RF_R9: 8K2; R_Axial_DIN0207_L6.3mm_D2.5mm_P7.62mm_Horizontal
RF_R11: 4K7; R_Axial_DIN0207_L6.3mm_D2.5mm_P7.62mm_Horizontal
RF_R12: 15K; R_Axial_DIN0207_L6.3mm_D2.5mm_P7.62mm_Horizontal
RF_SW1: SW_SPDT; SW_CuK_OS102011MA1QN1_SPDT_Angled
RF_U1: LM1889; DIP-18_W7.62mm_LongPads
RF_VL1: Sumida_73279

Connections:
/rf_mod/sub_rf_mod/2: J4B1.2, RF_C2.2, RF_D2.2 (A), RF_R1.2, RF_R10.2; also elsewhere on the board
/rf_mod/sub_rf_mod/3: J4B1.3, RF_U1.2 (R-Y); also elsewhere on the board
/rf_mod/sub_rf_mod/5: J4B1.5, RF_C5.2, RF_D1.2 (A), RF_R1.1, RF_R4.2, RF_R11.2, RF_U1.3 (CHROMA_BIAS); also elsewhere on the board
/rf_mod/sub_rf_mod/6: J4B1.6, RF_U1.13 (CHROMA_SUBCAR); also elsewhere on the board
/rf_mod/sub_rf_mod/7: J4B1.7, RF_U1.4 (B-Y); also elsewhere on the board
/rf_mod/sub_rf_mod/8: J4B1.8, RF_C4.2, RF_R2.2; also elsewhere on the board
GNDD: J4B1.1, RF_C1.2, RF_C2.1, RF_C8.2, RF_C9.2, RF_C11.2, RF_C13.2, RF_J1.S, RF_R3.1, RF_R4.1, RF_R7.2, RF_U1.5 (GND); also elsewhere on the board
unnamed: RF_C1.1, RF_C8.1, RF_JP1.1 (A), RF_R8.2, RF_R9.2, RF_U1.14 (RF_SUPPLY), RF_U1.16 (CHROMA_SUPPLY), RF_VL1.3
unnamed: RF_C3.1, RF_U1.1 (CHROMA_LEAD)
unnamed: RF_C3.2, RF_C4.1, RF_R3.2
unnamed: RF_C5.1, RF_R2.1, RF_U1.18 (CHROMA_LAG)
unnamed: RF_C6.1, RF_L3.1, RF_R5.2, RF_SW1.2 (B), RF_U1.7 (CHB_TANK2)
unnamed: RF_C7.1, RF_R12.1
unnamed: RF_C7.2, RF_R9.1, RF_R11.1, RF_U1.12 (VIDEO_IN)
unnamed: RF_C10.1, RF_L2.2
unnamed: RF_C9.1, RF_C10.2, RF_L1.1, RF_R7.1
unnamed: RF_C11.1, RF_J1.T, RF_L1.2
unnamed: RF_C12.1, RF_SW1.1 (A)
unnamed: RF_C6.2, RF_C12.2, RF_L3.2, RF_R6.1, RF_U1.6 (CHB_TANK1)
unnamed: RF_D2.1 (K), RF_R12.2, RF_U1.15 (SOUND_TANK), RF_VL1.1
unnamed: RF_L2.1, RF_R8.1, RF_U1.10 (CHB_OUTPUT)
VDDF: J4B1.4, RF_C13.1, RF_D1.1 (K), RF_JP1.2 (B), RF_R5.1, RF_R6.2, RF_R10.1; also elsewhere on the board

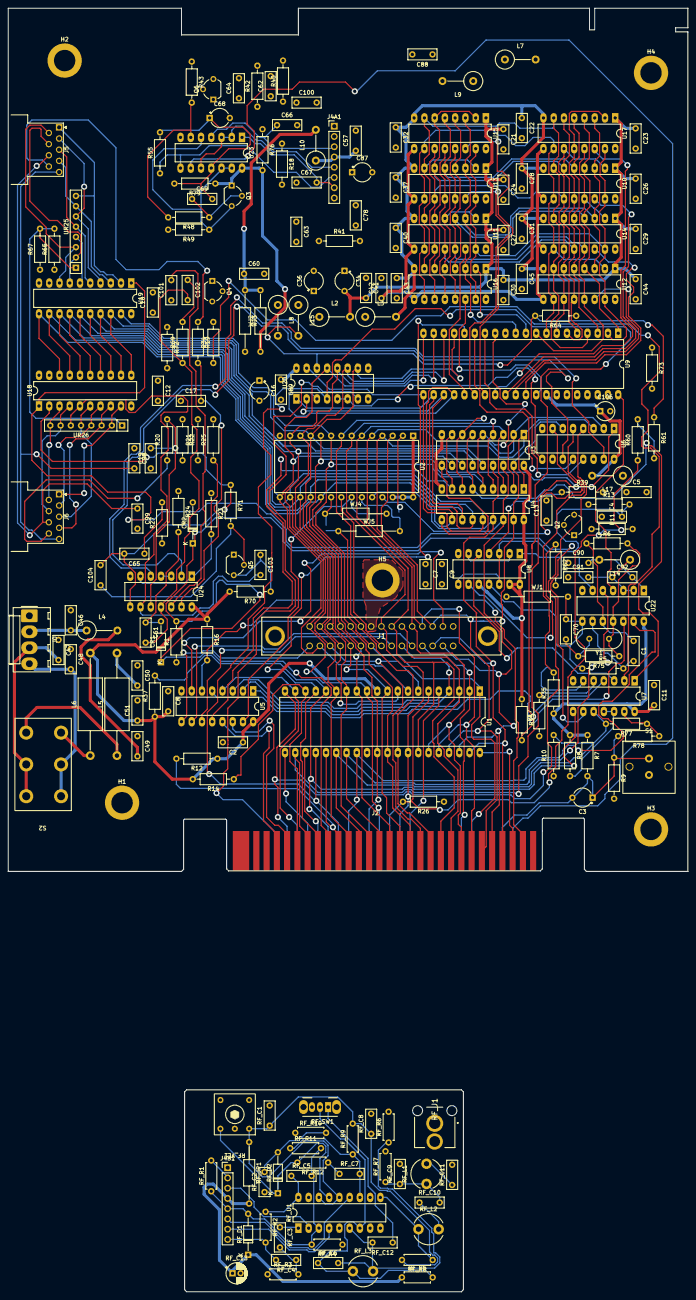
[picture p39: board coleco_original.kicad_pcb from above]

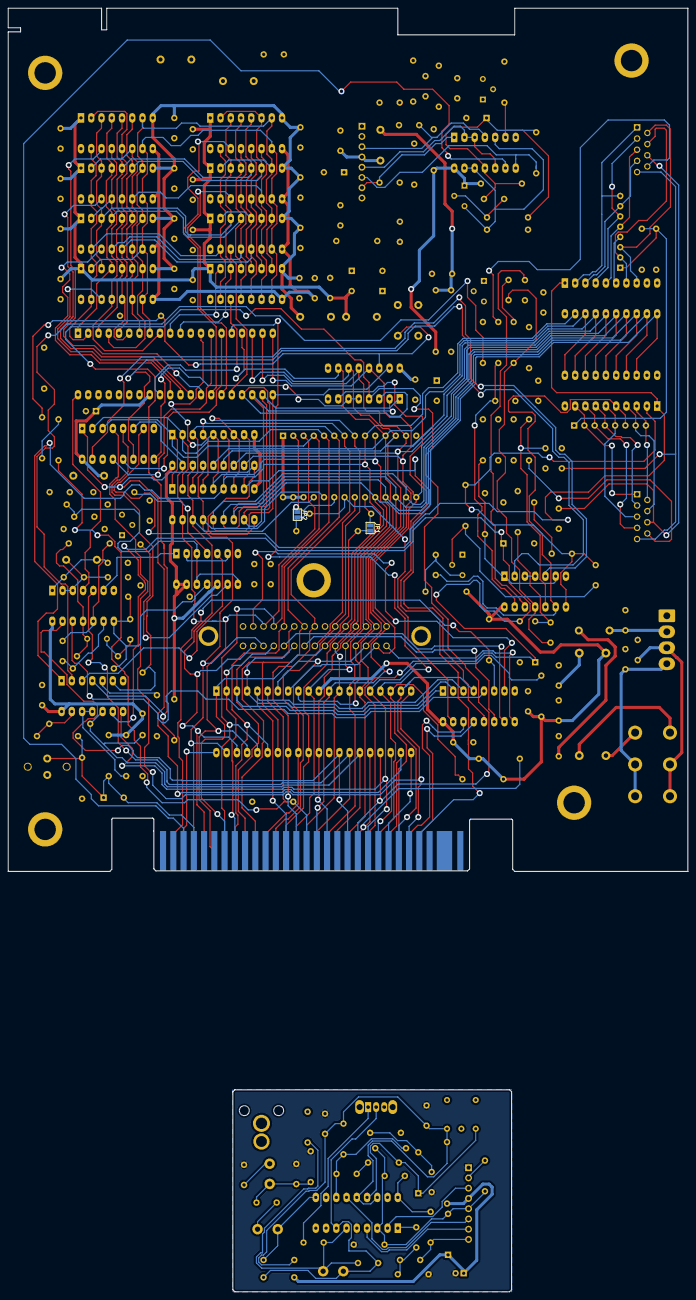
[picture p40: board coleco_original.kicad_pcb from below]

Board: 2 copper layers, 168.4 x 213.9 mm, 220 parts (2 on the bottom side), 183 nets.

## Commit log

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2022-12-28 first day of pcb trace, working pin by of the z80 cpu. Last pin completed: 7
    [coleco_original.kicad_sch, sound.kicad_sch]
2022-12-29 revised schematic into sheets for easier design. Looks much better.
    [clock_reset.kicad_sch, coleco_original.kicad_sch, controller.kicad_sch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]
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2022-12-30 changed all vintage library names to better represent future ideas. Removed parts not needed... for now. Updated schmematic symbols.
    [sound.kicad_sch, storage.kicad_sch, video.kicad_sch]
2022-12-31 Up to pin 29 on z80 done. Address 0 to 10 left. Only tracing to its end point for the most part. Each chip gets traced chip to chip in this manned
    [clock_reset.kicad_sch, coleco_original.kicad_sch, cpu.kicad_sch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]
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2023-01-02 added rf modulation schematic, added dram to vdp. Fixed +5vc to +5v
    [clock_reset.kicad_sch, coleco_original.kicad_sch, cpu.kicad_sch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]
2023-01-02 added u5 decoder lines, need to rename for chip selects that they actually are in future.
    [clock_reset.kicad_sch, coleco_original.kicad_sch, decoder_logic.kicad_sch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]
2023-01-02 added u6 decoder lines, renamed a few lines to make sense to there destination.
    [coleco_original.kicad_sch, controller.kicad_sch, decoder_logic.kicad_sch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]
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2023-01-03 fixed some more line names, added a expansion port io pin.
    [clock_reset.kicad_sch, coleco_original.kicad_sch, cpu.kicad_sch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]
2023-01-03 power supply added, controller circuit added. Controller is a very odd duck to say the least. Seems they wanted to have plenty of current, maybe due to the steering wheel attachement?
    [clock_reset.kicad_sch, coleco_original.kicad_sch, controller.kicad_sch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]
2023-01-03 started work on clock_reset_misc circuits. inverter u7 done, u8 added and starting work around U22.
    [clock_reset.kicad_sch, coleco_original.kicad_sch, controller.kicad_sch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]
2023-01-04 first version of clock-reset circuits. Its a bit complicated and will need some revisions.
    [clock_reset.kicad_sch, coleco_original.kicad_sch, psu.kicad_sch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]
2023-01-04 altered and did some cleanup of the way the wires were run. Finished expansion port routes to rf modulator. Added ext_psu for future external power supply design (will be an off the shelf psu block).
    [clock_reset.kicad_sch, coleco_original.kicad_sch, controller.kicad_sch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]
2023-01-04 added rf mod section, this is very rough. Has mistakes for sure.
    [coleco_original.kicad_sch, rf_mod.kicad_sch]
2023-01-04 RF modulator completed, rough draft complete. Next step is to clean-up all pages.
    [clock_reset.kicad_sch, coleco_original.kicad_sch, ext_psu.kicad_sch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]
2023-01-08 Cleanup clock-reset-invert schematic. Checked against wiki.console5.com/wiki/Colecovision. Had a inverter backwards (after cleanup it was obvious since its a standard circuit). Everything else checks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
    [clock_reset.kicad_sch, coleco_original.kicad_sch, cpu.kicad_sch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]
2023-01-08 cleanup on the controller schematic. Checked against wiki.console5.com/wiki/Colecovision. Found a mistake with INT line thanks to the wiki. R21/R22 is reversed between the schematics. Aka R21 is plac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
    [clock_reset.kicad_sch, controller.kicad_sch, sound.kicad_sch]
2023-01-08 cleaup of rf circuits. much better flow vs the original. Comparing to the wiki.console5.com/wiki/Colecovision shows many differences. Not sure I agree with it at all. Going to use the ADAM schematic 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
    [coleco_original.kicad_sch, rf_mod.kicad_sch, sub_rf_mod.kicad_sch]
2023-01-09 cleanup of power supply, and another pass at the RF circuit. Both look much better. The RF circuit just looks wrong though. Will need to check it over.
    [coleco_original.kicad_sch, io_ports.kicad_sch, psu.kicad_sch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]
2023-01-09 cleaned up RF circuit again, and used ChildOfCv schematic as a ref. Fixed a few mistakes. I didn't know his even existed. Its a very nice project. I didn't know it existed till I was googling some so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
    [clock_reset.kicad_sch, coleco_original.kicad_sch, rf_mod.kicad_sch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]
2023-01-09 added my refs so people will know where the 2nd phase of checks came from. its really helped the effort, the goal is to reverse the board from the original, and use online sources to check, and then 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
2023-01-10 all lines renamed, based most of the names from the coleco adam schematic. CS cart lines are my own, and the rest are from the wiki schematic for the controller... those will need to be checked.
    [clock_reset.kicad_sch, coleco_original.kicad_sch, controller.kicad_sch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]
2023-01-10 adjusted size of the sheets. added pcb version to the rev field. F.0... the 0 is for future fixes on my end. RF PCB is E.0.
    [clock_reset.kicad_sch, coleco_original.kicad_sch, controller.kicad_sch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]
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2023-01-16 added new libs for rest of the parts. some still need updating for correct parts, but for now they work. PCB import complete.
    [c-5530841-2-b-3d.ipt, c-5530841-2-b-3d.stp, clock_reset.kicad_sch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]
2023-01-16 created edge cut outline for coleco pcb. updated expansion connector edge cut to be the correct size (using a 0.8 mm cutting end in my mill).
    [coleco_original.kicad_pcb, coleco_original.kicad_sch, sub_rf_mod.kicad_sch]
2023-01-16 place a few components for an alignment check. changed edge cut back to 0.1. added new edge.cuts.mill layer for pcb mill edge cuts
    [coleco_original.kicad_pcb, sub_rf_mod.kicad_sch]
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2023-02-07 added a quick version of the RF board. Not checked at all.
    [coleco_original.kicad_pcb]
2023-02-12 fixed RF board placement, not perfect, but needs to align to new component sizes
    [coleco_original.kicad_pcb, sub_rf_mod.kicad_pcb, sub_rf_mod.kicad_sch]
2023-02-13 RF on main board components setup correctly.
    [coleco_original.kicad_pcb, coleco_original.kicad_sch, psu.kicad_sch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]
2023-02-14 did a small amount of pcb work, also finished component directions for the main board. RF pcb is still a mess and needs a second pass.
    [coleco_original.kicad_pcb, sub_rf_mod.kicad_sch]
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2023-02-22 added traces to parts of the clock gen/reset ic's
    [coleco_original.kicad_pcb, coleco_original.kicad_sch, psu.kicad_sch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]
2023-02-28 fixed a bug on the +5v line, added +5NF (no filter) net list names. Added traces to the ram, and inverter, and select ics.
    [coleco_original.kicad_pcb, coleco_original.kicad_sch, decoder_logic.kicad_sch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]
2023-03-02 added memory, eprom and sound lines. some video as well. fixed the cap size for polar. its a bit weird since they use 5 mm pin and 5mm body and bend out the leads.
    [clock_reset.kicad_sch, coleco_original.kicad_pcb, coleco_original.kicad_sch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]
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2023-03-13 added a new jack with matching pin names. started fixing drc errors. start working on power trace sizes.
    [coleco_original.kicad_sch, sub_rf_mod.kicad_sch]
2023-03-14 added new models, fixed the drc errors. changed power width.
    [clock_reset.kicad_sch, coleco_original.kicad_sch, controller.kicad_sch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]
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2023-03-14 added power cable pinout, cleanup finished on main page of schematic, now fits US letter page.
    [coleco_original.kicad_sch, ext_psu.kicad_sch, video.kicad_sch]
2023-03-17 added pads for switch and RF shield, RF shield still needs adjustment
    [coleco_original.kicad_sch, controller.kicad_sch, psu.kicad_sch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]
2023-03-17 fixed mount spacing, added labels, and added new version of reset switch.
    [coleco_original.kicad_sch, sub_rf_mod.kicad_sch]
2023-03-17 imporved power rails, added 3D models (primitives at this point till others can be made).
    [Coilcraft SLOT10 tunable.FCStd, Coilcraft SLOT10 tunable.stp, c-5530841-2-b-3d.ipt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]
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2023-03-20 some cleanup on the rf main circuit. tested out and reverted 10 mil to 12 mil spacing. Fails on cart connector.
    [coleco_original.kicad_sch, rf_mod.kicad_sch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]
2023-03-23 fixed cart for 12 mil isolation routing. Now minimum trace isolation is 12 mil. Trace width min is 12 mil. This is easier to build.
    [coleco_original.kicad_sch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]
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2023-03-25 adjusted connector and switch to remove ignored clearance errors
    [coleco_original.kicad_sch, sub_rf_mod.kicad_sch]
2023-03-25 adjust gnd iso width to better connect all grounds in video ram (20 down to 12mil)
    [sub_rf_mod.kicad_sch]
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2023-03-30 enlarged mount holes to match coleco, adjusted placement of two. adjusted traces for new holes.
    [coleco_original.kicad_sch]
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2023-04-03 fixed two resistors that were the wrong value wrong, 270. correct 120.
    [coleco_original.kicad_sch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]
2023-04-03 changed the board from the original so the control ports can be soldered from the bottom. standard dsub 9 bin connectors don't work on non-plated hole designs. All other parts can be soldered top and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
2023-04-03 added mounting holes, future proof the video section for jumper selection of voltages between 4516/4116 chips
    [coleco_original.kicad_sch, rf_mod.kicad_sch, sub_rf_mod.kicad_pcb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]
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2023-04-07 changed crystal a bit more to make double sided non-plated through hole designs easier. This time top traces rerouted to avoid shorts from the crystal body.
2023-04-08 updated schematic PDF, updated 3D image. Updated all gerber files, and small adjustments to the pcb to cleanup traces.
    [clock_reset.kicad_sch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]
2023-04-09 fixed cap value, adjusted rf lines on main board to make npt hole assembly easier
    [coleco_original.kicad_sch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]
2023-04-09 fixed value of resistors on RF board, fixed placement of resistors on RF board
    [coleco_original.kicad_sch, sub_rf_mod.kicad_sch]
2023-04-10 adjusting RF layout, seems to have issues with the previous layout with noise
    [sub_rf_mod-B_Cu.gbr, sub_rf_mod-B_Silkscreen.gbr, sub_rf_mod-Edge_Cuts.gbr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]
2023-04-11 fixed footprint lead size
    [sub_rf_mod-B_Cu.gbr, sub_rf_mod-B_Silkscreen.gbr, sub_rf_mod-Edge_Cuts.gbr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]
2023-04-12 pdf added, and changes to data bus to resolve shorting issues between cart and rom
    [coleco_original_main_only-B_Cu.gbr, coleco_original_main_only-B_Silkscreen.gbr, coleco_original_main_only-Edge_Cuts.gbr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]
2023-04-13 changed switch to one that is a better match for the old (larger)
    [coleco_original.kicad_sch, sub_rf_mod.kicad_pcb, sub_rf_mod.kicad_sch]
2023-04-14 update routing of rf board to fix loop over pin
    [sub_rf_mod-B_Cu.gbr, sub_rf_mod-B_Silkscreen.gbr, sub_rf_mod-Edge_Cuts.gbr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]
2023-05-01 changed a few traces, and updated a few parts. cleanup to make building easier so resistors don't have vias under them for npth builds
    [clock_reset.kicad_sch, coleco_original.kicad_sch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]
2023-05-01 changed clock line so it wouldn't keep the resistor out of place on npth builds
    [coleco_original.kicad_sch]
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2023-05-10 updated switch to fix isolation size. fixed some traces to prevent shorts when being build at home with mills or etching methods.
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2023-05-21 fixed pad size for switch
    [coleco_original_main_only.step, main_exports_missing.FCStd]
2023-05-22 fixed 5v via so it doesn't hold up the resistor
    [coleco_original_main_only-B_Cu.gbr, coleco_original_main_only-B_Silkscreen.gbr, coleco_original_main_only-Edge_Cuts.gbr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]
2023-05-23 fixed some t-tech edge cut for the main board.
    [coleco_original_main_only-B_Cu.gbr, coleco_original_main_only-B_Silkscreen.gbr, coleco_original_main_only-Edge_Cuts.gbr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]
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2023-05-23 fixed the switch for the sub-rf board to match the original coleco for chan 3/4 selection
    [sub_rf_mod-B_Cu.gbr, sub_rf_mod-B_Silkscreen.gbr, sub_rf_mod-Edge_Cuts.gbr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]
2023-05-25 first commit of verison 1.0.0, missing documents for signals and 3D enclosure.
    [clock_reset.kicad_sch, coleco_original.kicad_sch, controller.kicad_sch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]
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2023-05-28 added new kicad 3d model of pcb... coleco_original3.iam is the best. odd bug that the switch comes out clear
    [5530841-2.iam, Assembly1.0004.iam, Assembly1.0006.iam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]
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2023-06-19 3D printed part adjust, fix cart position.
    [Assembly1.0006.iam, Assembly1.0009.iam, Assembly1.iam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]
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2024-03-25 fixed for github
    [controller.kicad_sch, org_case_psu_connector.0001.ipt, org_case_psu_connector.ipt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]
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2024-11-08 update gerbers in zip files to remove edge.cuts.mill. This caused issues with JLCPCB per user Tekman on Atari Age
    [coleco_original_main_only-B_Adhesive.gbr, coleco_original_main_only-B_Courtyard.gbr, coleco_original_main_only-B_Cu.gbr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]
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2024-12-02 remove solder mask from edge connector (thanks to Tekman@AtariAge for pointing this out), update gerbers and version
    [coleco_original_main_only-B_Adhesive.gbr, coleco_original_main_only-B_Courtyard.gbr, coleco_original_main_only-B_Cu.gbr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]
